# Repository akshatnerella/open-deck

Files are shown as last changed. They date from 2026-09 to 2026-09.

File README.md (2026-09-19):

# Open Deck

An open-source physical control surface for terminal AI coding agents.

Four project keys, a tuning dial, and a small face that tells you what your
agents are up to.

Built around **tmux**: the four animal keys are four tmux sessions, the encoder
steps through the panes inside one. Harness-agnostic — it works with Claude
Code, Grok CLI, OpenCode, or a plain shell, because it reads tmux rather than
integrating with any of them.

---

## Key map

```
 TERM   MIC    FOX    PNDA
 ENTER   X     CAT    OWL
```

| Key | Tap | Double-tap | Hold |
|---|---|---|---|
| **FOX OWL CAT PNDA** | go to that session — creates it if new | | list its panes |
| **TERM** | start the agent in this pane | new pane beside | new window |
| **X** | interrupt — `C-c` in a shell, `Escape` in an agent | close the pane | |
| **ENTER** | Enter — or go to the highlighted pane | | |
| **Encoder** | move through panes | | |

**One chord:** hold **ENTER** and double-tap **TERM** to split *below* instead
of beside.

Three behaviours worth knowing:

**ENTER, X and MIC change meaning with the pane.** `C-c` interrupts a shell but
`Escape` interrupts an agent without killing it; voice is `Space` in Claude and
`Ctrl-Space` in grok. In a plain shell MIC sends nothing at all — there's no
voice mode to toggle, and a stray space would type one.

**Starting an agent somewhere new is two presses:** double-tap TERM for an
empty pane, then tap TERM to fill it. One key never rearranges your screen as a
side effect of launching something.

**Tap X to stop it, double-tap X to close it.** Closing runs `exit`, so the
shell cleans up and tmux ends the session if it was the last pane. It refuses
while a program is running and toasts `still running` — tapping X already
interrupts, so the sequence is tap then double-tap.

---

## Setting it up on a Mac

Nothing to install for the host side: the bridge is **stdlib-only** and runs on
the Python that ships with macOS.

```bash
git clone git@github.com:akshatnerella/open-deck.git
cd open-deck
./open-deck                    # that's the whole install
```

You need **tmux** (`brew install tmux`) and an agent CLI on your `PATH`.

To have it start at login:

```bash
./scripts/autostart install    # uninstall / status also work
```

This copies the bridge to `~/Library/Application Support/OpenDeck` rather than
pointing at your checkout, because macOS blocks launchd agents from reading
`~/Documents`. Re-run it after pulling. Logs go to `~/Library/Logs/opendeck.log`.

### Flashing the deck

Only needed on a new board, not on a new Mac — the firmware lives on the
device.

```bash
arduino-cli core install esp32:esp32 \
  --additional-urls https://raw.githubusercontent.com/espressif/arduino-esp32/gh-pages/package_esp32_index.json
arduino-cli lib install "Adafruit GFX Library" "Adafruit SH110X"

arduino-cli compile --fqbn esp32:esp32:XIAO_ESP32S3 v0/firmware/open_deck
arduino-cli upload  --fqbn esp32:esp32:XIAO_ESP32S3 -p /dev/cu.usbmodemXXXX v0/firmware/open_deck
```

The eye renderer is vendored as `pixie_eyes.h`, so there's no third library to
install. See the notes at the top of that file for what's patched and why.

> **Using the Arduino IDE instead?** It keeps a *separate* config from
> `arduino-cli` — same sketchbook, different board packages. Add the Espressif
> URL under **Settings → Additional boards manager URLs**, then quit and reopen
> the IDE, or the board won't appear even though it's installed.

> **Only one thing can hold the serial port.** Close the IDE's Serial Monitor
> before running the bridge, and stop the bridge before flashing.

### Configuration

None required. The four keys already mean `fox`, `owl`, `cat`, `pnda`.

Optional, at `~/.config/opendeck/config.json`:

```json
{
  "harness": "grok",
  "sessions": ["webapp", "api", null, null]
}
```

`harness` is one of `claude`, `grok`, `opencode`, `codex`, `aider` — it picks
the launch command and the right keystrokes for ENTER, X and MIC. Detection
stays permissive: a deck set to grok still shows a Claude pane as working,
because the setting decides what a key *launches* and must not make the display
lie about what's running.

---

## What it does

**A key means the same session every time.** FOX is `fox`, CAT is `cat`. If it
doesn't exist yet, pressing the key creates it. Nothing is discovered, nothing
gets reshuffled — a physical button whose meaning moves is worse than no button.

**Hold a key to see inside.** The panel lists that session's panes: a mark for
shell or agent, the active one flagged, and whatever each pane is best called.
Claude Code reports a session title (`open deck`), which beats anything the deck
could infer. A plain terminal shows as `zsh` rather than being hidden.

**The dial browses.** In the session you're in it follows along — your Mac is
the preview. Hold an animal and it browses *that* session without moving you; a
dial shouldn't yank you out of what you're reading. ENTER goes to the
highlighted pane, switching sessions if it's elsewhere. Stop touching it and the
list gives up after a couple of seconds and goes back to Pixie. It's a
look-and-go tool, not a mode.

**The home screen is Pixie, and only Pixie.** She has the whole panel. Her
expression is driven by tmux state — concerned when something wants attention in
a session you aren't watching, happy when an agent finishes, curious while one
works.

**A live deck never lies about being live.** The bridge pings the display every
couple of seconds; if that stops, Pixie's eyes close and a `host offline` toast
appears within about five seconds, rather than leaving a stale face on screen.

### Attention

When a session you aren't looking at rings a bell or shows activity, the deck
inverts the whole screen three times, Pixie turns to a scowl, and a toast names
the session (`OWL wants you`). A standing alert re-pulses every 10s.

`invertDisplay()` is a single command byte rather than a framebuffer write, so
flashing is effectively free next to the ~29.5ms cost of a redraw.

A piezo buzzer would still beat any visual signal for catching attention when
you're looking elsewhere entirely — v1's PCB should populate one.

---

## Architecture

```
┌───────────────┐  USB serial  ┌─────────────────┐    tmux     ┌──────────┐
│   Open Deck   │─────────────▶│    opendeck     │────────────▶│ sessions │
│ XIAO ESP32S3  │  EVT / HB    │  (host bridge)  │  + Ghostty  │  panes   │
│               │◀─────────────│                 │◀────────────│  agents  │
└───────────────┘ FACE/TOAST/  └─────────────────┘   polling   └──────────┘
                  PEEK/LIST
```

The firmware knows nothing about tmux or any harness — it emits semantic events
(`EVT KEY_AGENT2 HOLD`) and renders whatever the host pushes back. All the
knowledge lives in the bridge, where it's testable without hardware.

**Everything is derived from tmux**, which already tracks per-window activity
and bell flags — the "something happened where you aren't looking" signal, free,
for every harness. No hooks, no `settings.json` edits, no screen scraping.

Keys reach panes with `tmux send-keys`: it hits the right pane **without
stealing focus** and needs no macOS Accessibility permission. The deck is
deliberately **not** a USB keyboard — see
[docs/decisions/no-hid.md](docs/decisions/no-hid.md) for why that was built
twice and removed twice.

---

## Versions

| | |
|---|---|
| **[v0](v0/)** | Hand-wired breadboard prototype. USB-tethered, off-the-shelf parts. **Built and working.** Start here |
| **v1** | Custom PCB with the XIAO reflow-mounted via castellated pads, proper diode matrix, piezo buzzer. Not started |

See [`v0/README.md`](v0/README.md) and [`v0/BOM.md`](v0/BOM.md).

---

## Status

| | |
|---|---|
| Hardware: display, encoder, 8-key matrix | ✅ validated |
| Firmware: input on core 1, rendering on core 0 | ✅ built |
| Host bridge: tmux navigation, peek, Pixie | ✅ built, 211 tests |
| Claude Code and Grok CLI | ✅ detection and keymaps measured on both |
| OpenCode / Codex / Aider | ⏳ patterns written, unverified against those CLIs |
| Custom PCB | 📋 v1 |

Tests run on stock macOS Python with no dependencies:

```bash
cd v0/bridge && python3 -m unittest discover -s tests
```

---

MIT licensed. Not affiliated with Anthropic, xAI, or any harness vendor.

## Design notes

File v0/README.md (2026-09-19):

# Open Deck v0

The hand-wired prototype: breadboard, off-the-shelf parts, USB-tethered.
**Everything here is built and verified working on real hardware.** The
`FACE`/`LIST` wire protocol and the glance layer are new — built and covered
by the host-side test suite, but not yet re-verified against the physical
deck.

v1 will replace the breadboard with a custom PCB — see the root
[README](../README.md).

---

## Contents

```
v0/
├── BOM.md                  parts list, wiring, print notes
├── firmware/
│   ├── open_deck/          THE firmware - flash this
│   │                       (pixie_eyes.h is a vendored, patched RoboEyes)
│   └── diagnostics/        bring-up sketches (i2c scan, key probe, ...)
├── bridge/
│   ├── opendeck/           host bridge (stdlib only)
│   └── tests/              211 offline tests, no hardware needed
├── cad/
│   ├── stl/                printable shells + 8 keycaps
│   └── dxf/                badge icon outlines (for remixing keycaps)
└── tools/
    └── serial_mirror_gui.py   mirrors the deck UI on your laptop
```

---

## Build order

1. **Print** the shells and keycaps — `cad/stl/`, see [BOM.md](BOM.md)
2. **Wire** it up — pin map in [BOM.md](BOM.md)
3. **Flash** the firmware:
   ```bash
   arduino-cli compile --fqbn esp32:esp32:XIAO_ESP32S3 firmware/open_deck
   arduino-cli upload  --fqbn esp32:esp32:XIAO_ESP32S3 -p /dev/cu.usbmodemXXXX firmware/open_deck
   ```

   > Build with the board's default USB mode (`hwcdc`). It uses the hardware
   > USB-Serial/JTAG peripheral, so the port exists whatever the firmware does
   > — a bad flash can always be recovered with another flash.
4. **Verify** the wiring before going further:
   ```bash
   arduino-cli upload --fqbn esp32:esp32:XIAO_ESP32S3 -p PORT firmware/diagnostics/i2c_scanner
   ```
   The OLED must appear at `0x3C`. If nothing shows up, it's the wiring or a
   charge-only USB cable — not the code.
5. **Run the bridge.** There is no install step — it is stdlib-only and runs
   on the Python macOS ships:
   ```bash
   ./open-deck --command grok
   ```

Everything is read from tmux — no hooks, no `settings.json` edits. Run your
agents under `tmux` and the deck picks them up automatically.

6. **Optionally run it at login**:
   ```bash
   ./scripts/autostart install     # uninstall / status also work
   ```
   Installs a launchd agent that restarts on crash and logs to
   `~/Library/Logs/opendeck.log`. It copies the bridge to
   `~/Library/Application Support/OpenDeck` — macOS blocks launchd agents from
   reading `~/Documents`, so pointing one at a checkout there fails. Re-run
   after pulling.

Optional config at `~/.config/opendeck/config.json`:

```json
{
  "launch_command": "grok",
  "sessions": ["webapp", "api", null, null]
}
```

---

## Diagnostics

If something misbehaves, these isolate it faster than guessing:

| Sketch | Answers |
|---|---|
| `i2c_scanner` | Is the display on the bus at all? |
| `raw_io_test` | Live pin states — is a key or the encoder actually wired? |
| `key_test` | Single-key press detection |
| `encoder_menu_test` | Encoder rotation with the debounced lookup-table decoder |
| `open_deck_validate` | Display + encoder + one key together |
| `open_deck_matrix` | Full 8-key matrix with an on-screen grid |
| `pixie_face_test` | Pixie cycling every emotion, standalone |

`tools/serial_mirror_gui.py` renders the deck's UI on your laptop from the
same serial stream — useful for telling "the display is slow" apart from
"the firmware is slow".

```bash
python3 tools/serial_mirror_gui.py
```

> The bridge itself needs nothing, but this tool is the exception: it needs
> `pyserial` and a real Tk. Apple's bundled Tcl/Tk 8.5.9 renders a blank
> window. `brew install python-tk@3.13`, `pip install pyserial`, and use that
> interpreter.

---

## Tests

```bash
bridge/tests/run_tests.sh
```

132 tests covering gesture timing, slot assignment, tmux actions, presence
resolution, pane-list formatting, config loading and event parsing. No
hardware or tmux required — everything is driven through fakes.

---

## Hard-won notes

Things that cost real debugging time, so you don't repeat them:

- **The display is SH1106, not SSD1306.** An SSD1306 driver renders
  plausible-looking garbage rather than failing cleanly.
- **Column order is `D7 D8 D9 D10` left to right** — the reverse of what the
  wiring notes implied. It was determined by pressing keys and reading back
  what the device reported. Measure, don't derive.
- **Serial writes must not block.** ESP32-S3 native USB CDC blocks once its TX
  ring fills with no host reading. Inline `Serial.print` in the main loop then
  stalls the key scan *and* the display. The firmware drops lines instead.
- **Don't redraw the OLED on a timer.** A full-frame I2C push is ~30ms; doing
  it 30×/second regardless of activity starves everything else. Redraw on
  change only.
- **`pinMode()` is expensive on ESP32.** Toggling rows between `OUTPUT` and
  `INPUT` every scan was slow enough to make the encoder feel laggy;
  `OUTPUT_OPEN_DRAIN` set once gives the same protection for free.
- **Scope input debouncing to the keys that need it.** A double-tap window
  held *every* tap for 350ms, though only one key had a double binding - so
  seven keys paid for a feature they never used. Latency you add deliberately
  is still latency.
- **A full OLED flush blocks for 29.5ms.** Sharing a thread with input means
  the encoder is never sampled during a flush, and detents get *dropped* —
  which reads as inconsistency, not lag. Rendering is pinned to core 0 and
  `loop()` owns core 1. Measured: 29,500µs blind window → 390µs.
- **Stay on the default `hwcdc` USB mode.** It was briefly built as
  `USBMode=default` (TinyUSB) to get HID, which cost three separate hazards:
  the port renamed between app and bootloader so uploads failed on the first
  pass, and a firmware that failed to bring up USB made its own port vanish.
  Under `hwcdc` the port is dedicated silicon and exists whatever the firmware
  does, so a bad flash is always recoverable with another flash.
- **A charge-only USB-C cable** will power the board and blink the charge LED
  while enumerating nothing. The LED tells you nothing about the data link.
- **A status display that lies is worse than none.** Without a host keepalive
  the deck happily showed a stale face forever. Any received command is a
  liveness tick; 5s of silence closes Pixie's eyes.

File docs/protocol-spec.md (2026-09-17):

# Open Deck — Wire Protocol v2

USB CDC serial, 115200 baud, newline-delimited ASCII, bidirectional.

Human-readable on purpose: `screen /dev/cu.usbmodemXXXX 115200` is a complete
debugging setup.

---

## Device → host

```
EVT <KEY_NAME> DOWN|HOLD|UP
EVT ENCODER <+1|-1>
HB <uptime_ms>
```

### Keys

| Name | Position | Bound to |
|---|---|---|
| `KEY_TERM` | R1C1 | launch agent / split / new window |
| `KEY_MIC` | R1C2 | voice toggle (Space; `C-Space` on grok) |
| `KEY_AGENT1` | R1C3 | Fox |
| `KEY_AGENT4` | R1C4 | Panda |
| `KEY_ENTER` | R2C1 | Enter |
| `KEY_CANCEL` | R2C2 | interrupt / close pane |
| `KEY_AGENT3` | R2C3 | Cat |
| `KEY_AGENT2` | R2C4 | Owl |

`HOLD` fires at 400ms while a key is still down. The host runs the *hold*
action on `HOLD`, and the *tap* action on `UP` **only if no `HOLD` was seen**
since the matching `DOWN`. Double-tap is resolved host-side within a 350ms
window. One physical press yields exactly one action.

---

## Host → device

```
FACE <alert|busy|done|calm>
TOAST <text>
LIST <title>|<row>|<row>|...
PEEK <cursor>|<bar>|<row>|...
```

`FACE` sets Pixie's expression, one of four wire states. The old
`idle`/`working`/`attention`/`done`/`active`/`asleep` set is gone —
`idle`/`active` rendered identically and `asleep` was presentation rather
than a state of its own, so the daemon now resolves everything down to
`alert`, `busy`, `done`, or `calm` (see `presence.py`).

`TOAST` shows one line for 1.8s, replacing the face, then the face resumes.

`LIST` shows the pane list for whichever session the encoder or a project key
just brought into view — a title row plus up to five pane rows — held for
1.2s, then decaying back to the face. Summon sends `LIST` too, in place of a
toast, because naming the destination and showing its contents in one shot is
strictly more useful than a line of text.

`PEEK` leads with the **cursor**: the row index the device draws inverted, or
`-1` for no selection. Inverting a row says "ENTER goes here" instantly and
costs no width, which a marker character would.

`PEEK` then carries rows, because the device positions each
by role rather than stacking them: an inverted **bar** naming the key, a
**headline** the panel is built around, and a small **detail** line. The
headline is drawn at double size when it fits in 10 characters and normal size
otherwise, so a short session name reads across a desk and a long one still
reads at all.

`PEEK` shows what a held key will do, replacing everything else on screen. It
has no timeout: it goes up when the hold registers and comes down when the key
is released, so it tracks the finger. An empty payload clears it.

Peeking is non-destructive by design. Holding used to interrupt that slot's
session; a destructive action on the same gesture teaches people not to
explore, which defeats the point of a self-documenting device.

`LIST` travels as **one line**, never a begin/item/end sequence. A multi-line
render can be interrupted mid-draw by whatever the host sends next, leaving a
half-built screen on the panel; a single line either arrives complete or not
at all. The host does every formatting decision — windowing to five rows with
the active pane always kept visible, the `>` active marker, tmux window
flags, label truncation and delimiter sanitisation, all in `panes.py` — and
hands the firmware one `|`-delimited string. The firmware only splits on `|`
and draws each field verbatim; it makes no layout decisions of its own.

Toast and list both **replace** rather than overlay the face: RoboEyes'
`drawEyes()` flushes the framebuffer itself, so an overlay would need a
second full-frame write every frame. Each is drawn and flushed once and then
costs nothing until it expires.

---

## Liveness

The host sends `FACE <state>` every 2s regardless of whether the state
changed — a keepalive, not just a state push. The firmware treats **any**
received command as proof the host is alive; after 5s of silence it closes
Pixie's eyes and shows a `host offline` toast. This is deliberate: without a
keepalive the deck would happily keep showing a stale face forever after the
daemon died, and a status display that can go stale silently is worse than no
display. `lastHostCommand` is seeded at boot, so a deck powered on before the
daemon connects doesn't slam its eyes shut in the first few seconds.

An offline deck that stays offline blanks the panel entirely after 15
minutes, to avoid burning a static image into the mono OLED.

---

## Hardware notes

Verified by pressing R1C1..R2C4 in sequence and reading back what the device
reported:

| | |
|---|---|
| Rows | `D0` (row 1), `D1` (row 2) |
| Cols | `D7 D8 D9 D10` — **left to right** |
| Display | SH1106 128×64, I2C `0x3C`, on `D4`/`D5` |
| Encoder | CLK `D3`, DT `D6`; push-switch dead/unused |

Column order is the reverse of what the wiring diagram suggests. It was
measured, not derived. Don't re-derive it.

---

## Three constraints the firmware is built around

**Rendering runs on the second core.** A full SH1106 flush blocks for
**29.5ms** (measured), and RoboEyes wants a frame every 20ms — so on one
thread the display saturates the loop and the encoder is never sampled during
a flush. Detents last a few milliseconds, so they were not arriving late, they
were being *dropped*. Rendering is pinned to core 0; `loop()` owns core 1 for
input alone. Measured effect: worst input blind window 29,500µs → 390µs, loop
rate 1,100/s → 3,704/s.

**Serial writes drop rather than block.** ESP32-S3 native USB CDC blocks once
its TX ring fills with no host reading. `emit()` checks
`Serial.availableForWrite()` first. An unguarded `Serial.printf` was measured
stalling the loop for 1.8s while no host was attached.

**Rows are `OUTPUT_OPEN_DRAIN`.** LOW sinks, HIGH releases rather than
sources, so two keys sharing a column across both rows cannot short one row's
output into the other.

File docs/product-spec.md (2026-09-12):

# Open Deck — Design Notes

Why the device is shaped the way it is. For protocol details see
[protocol-spec.md](protocol-spec.md); for building one see
[../v0/README.md](../v0/README.md).

---

## The idea

Running several coding agents at once, the bottleneck isn't typing — it's
**context switching**. Which project was that in? Which pane is the agent in?
Where did I leave the tests running?

The deck maps that onto hardware you can hit without looking:

- **Four animal keys → four tmux sessions.** Coarse: which project.
- **Encoder → panes within that session.** Fine: which terminal.

The key insight, and the one that came from the user rather than the design:
**tmux sessions are a real thing you already have.** An earlier version
invented "agent sessions" as an abstraction and asked you to adopt it. Mapping
to tmux instead means the deck fits an existing workflow rather than replacing
one, and it makes the hardware's job legible — a preset button and a tuning
dial, like a radio.

---

## Why tmux does most of the work

tmux already tracks, per window, whether there's been **activity** or a
**bell** since you last looked. That's precisely the "something happened where
you aren't watching" signal the device needs — available from one subprocess
call, with no agent integration, no hooks, and no screen scraping.

An earlier design got this from Claude Code's hook system. That worked, but it
was Claude-Code-specific, needed `settings.json` edits, and broke entirely
under `--dangerously-skip-permissions`. tmux gives the same signal for every
harness for free.

---

## Pixie

The face is [Pixie](https://github.com/akshatnerella/pixie), drawn
procedurally by RoboEyes — the same character, ported from her 320×240 colour
panel to the deck's 128×64 mono OLED. Her expression is derived from tmux
state, evaluated in strict priority order so two simultaneously-true signals
can't make the face flap:

| Priority | State | Trigger |
|---|---|---|
| 1 | `attention` | activity/bell in a session you are **not** in |
| 2 | `done` | an agent that was running here stopped |
| 3 | `working` | something is running in the current session |
| 4 | `active` | you touched the deck (4s linger) |
| 5 | `idle` | shells only |
| 6 | `asleep` | 5 min untouched, or no sessions |

`done` is explicitly non-latching, or she'd stay grinning forever.

Notifications are **toasts**: one line, 1.8s, replacing the face. Subtle by
construction — they interrupt briefly rather than becoming permanent chrome.

---

## Things learned the hard way

Each of these cost real debugging time and is now pinned by a test or a
comment in the code.

**The display was eating the encoder.** A full SH1106 flush blocks 29.5ms;
RoboEyes wants a frame every 20ms. On one thread the encoder was never sampled
during a flush, so detents weren't delayed — they were dropped. Fixed by
pinning rendering to the second core. This looked like host-side lag and
wasn't; measuring the host first (12ms/poll, 7ms/detent) ruled it out before
any code changed.

**Claude Code reports its version as the process name.** `pane_current_command`
returns `2.1.261`, not `claude`. An allowlist of binary names silently misses
every running agent. Matched by shape as well as name.

**Column order was mirrored.** Physical left-to-right is `D7 D8 D9 D10`, the
reverse of the wiring diagram. Determined by pressing keys in sequence and
reading back the reported names. Guessed twice, wrong twice; measuring took one
round.

**Ghostty needs `-e` with separate argv entries.** `--args -e "tmux attach -t x"`
opens a window that runs nothing. And it uses non-native fullscreen, so
`AXFullScreen` reads `false` even when fullscreen — a "toggle unless already
fullscreen" check exits fullscreen every time. Fullscreen is set at launch
only.

**Never type into a busy pane.** `launch_agent` refuses when the pane is
running a program; injecting a command into someone's editor is unrecoverable.
The double-tap split path skips the check because a fresh pane is always an
idle shell.

---

## Not built

**Approvals.** A physical approve/deny button for agent permission prompts was
designed and built, then removed: it depends on the harness *asking*, and the
day-to-day launch command here is `grok`, which does not gate tool use.
The two are mutually exclusive by construction. The design notes are in git
history if that changes.

**A buzzer.** The deck still can't get your attention when you aren't looking
at it; a flashing face in peripheral vision is a weak signal. One chirp on
"agent blocked" would be worth more than every visual affordance here. v1's PCB
should populate one.

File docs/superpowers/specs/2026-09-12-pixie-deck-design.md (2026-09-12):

# Pixie Deck — product design

**Status:** proposed
**Date:** 2026-09-12
**Supersedes:** the "control surface for tmux" framing in `docs/product-spec.md`

Turns the deck from a tmux accessory into a desk product: four projects, four
keys, a character who tells you how they are doing. tmux stays — as plumbing
the owner never sees.

---

## Why it currently feels like a tool

Three concrete things, all fixable:

**1. It assumes tmux fluency.** `SlotTable` binds keys to sessions that already
exist. You create sessions, you name them, and the deck finds them. A key
pointing at nothing does nothing — so the device is inert until you have
already done the work by hand.

**2. Setup is a text file.** Pinning a slot means editing
`~/.config/opendeck/config.json` and restarting. Nothing about the physical
object participates in its own configuration, even though it has a screen, a
scroll wheel, and eight buttons.

**3. Every feature is a tmux command wearing a costume.** `summon` is
`switch-client`. The encoder is `select-pane`. The animals are decoration on
top of a keybinding you already had. There is no reason to want the object.

The fix is one decision: **the deck owns the projects, not the sessions.**

---

## The reframe

> Four keycaps. Four projects. Press one and you are working on it.

A slot is a **project** — a directory with a name and an animal. The deck
creates its session, opens the terminal, launches the agent, and remembers.
The owner never types `tmux`, never names a session, never edits a config.

| | Tool (today) | Product |
|---|---|---|
| A key means | a tmux session that exists | a project you work on |
| Empty key | does nothing | offers to set itself up |
| Binding | edit JSON, restart | encoder + press, on the device |
| Requires | knowing tmux | knowing which project you want |
| tmux is | the interface | an implementation detail |

Everything below follows from that.

---

## First run

The moment that decides whether this is a product. Plug in a deck that has
never been used:

```
1.  Pixie wakes, stretches, blinks.          "hello"
2.  The slot strip shows four empty pens.    · · · ·
3.  Press any animal key.
4.  The picker opens: recent git repos,
    most-recently-touched first.             turn to choose
5.  Press to confirm.
6.  The deck creates the session, opens the
    terminal, launches the agent.            FOX -> open-deck
```

Under a minute from plugging in to an agent running, with no typing. That is
the demo.

**Project discovery** scans for git repositories under the usual roots
(`~/Developer`, `~/Documents`, `~/src`, `~/code`, `$HOME`), ranked by most
recent commit — the same ordering an editor's "recent projects" uses, and it
is right nearly every time. No index, no daemon config: the scan runs when the
picker opens and caches for the session.

**Binding is remembered** in `~/.config/opendeck/decks.json`, written by the
deck, not by the owner. It is a cache with an obvious shape, not a config file
with a schema to learn. Deleting it costs one re-pick.

---

## The display, as a designed system

Five screens. Every pixel has an owner, and transitions between them are
defined rather than incidental.

### Home — Pixie, plus the fleet at a glance

```
+---------------------+
|                     |
|      ^   ^          |
|     ( o   o )       |    Pixie: 48px
|        ---          |
|                     |
+---------------------+
| FOX. OWL@ CAT! PNDA |    slot strip: 16px
+---------------------+
```

The slot strip is the product's whole value in one row: four projects, four
states, readable from across a desk without focusing your eyes.

| Glyph | State |
|---|---|
| (blank) | slot is empty |
| `.` | idle — a shell, nothing running |
| `@` | working — an agent is busy (animates) |
| `!` | needs you — blocked, or asking |
| `*` | done — finished since you last looked |

Pixie's expression is the same information at lower resolution: one glance
tells you *whether* anything needs you, the strip tells you *which*.

### Peek — hold any key

Holding a key shows what it will do, laid out in the same 2×2 arrangement as
the physical keys under your other hand. A chord system nobody can discover is
a party trick; this makes the device teach itself, and removes the manual.

```
Hold FOX:            +---------------------+
                     | FOX  open-deck      |
                     | working  ctx 62%    |
                     |---------------------|
                     | new    | interrupt  |
                     | speak  | approve    |
                     +---------------------+
```

Release without a second key and nothing happens — peeking is free, which is
what makes it safe to explore.

### Picker — encoder

A list bound to the encoder: projects when a slot is empty, panes when it is
not. Press to commit, any other key to cancel.

### Alert — something needs you

Pixie scowls, the strip marks the slot, a line names it. Latches until
acknowledged, because the whole point is that you were not looking.

### Sleep

After five idle minutes the panel blanks except for Pixie breathing. The deck
is furniture that occasionally has something to say, not a dashboard demanding
attention.

---

## Input grammar

The physical layout is already right and nobody planned it:

```
TERM   MIC     FOX   PNDA        left hand: verbs
ENTER  CANCEL  CAT   OWL         right hand: targets
```

Verbs under one hand, targets under the other. That is a two-handed chord
keyboard, so the grammar is **verb + target**:

| Input | Meaning |
|---|---|
| Tap target | go to that project (set it up if empty) |
| Hold target | peek: status + what the verbs will do |
| Hold target, turn encoder | scrub that project's panes without leaving yours |
| Hold target, tap verb | **apply the verb there without going there** |
| Tap verb | apply to where you are |
| Turn encoder | move between panes here |
| Hold TERM, turn encoder | command palette |

The fourth row is the one tmux cannot do and the reason to own the object:
**interrupt the agent in CAT while you keep reading OWL.** Every keybinding
alternative requires switching first.

Double-tap stays reserved for one shortcut per key, assigned from real use
rather than invented now. Today's `KEY_TERM` double-tap-to-split is the
template.

### One thing to fix

Slot numbering does not match reading order: `FOX PNDA / CAT OWL` on the keys,
but slots 0–3 are `FOX OWL CAT PNDA`. Harmless internally, wrong the moment a
screen lists them in slot order. Renumber to match what the eye sees.

---

## Pixie as the product, not the paint

She already earns her place: her expression is derived from real state, in
strict priority order, so two true signals cannot make the face flap. Three
additions make her the reason to keep the thing on a desk.

**She reacts to you, not just to the agents.** Coming back after ten minutes
away should look different from never having left. The deck knows — it sees
key events.

**She has an opinion about time.** An agent working for two minutes is normal;
one stuck for twenty is worth a worried look, and nothing in the current state
machine can express that.

**She is never wrong.** The existing offline rule — eyes closed when the host
stops talking — is the single most important thing about her, and it stays.
A face that keeps smiling when it has no idea what is happening is worse than
a blank screen, because it is confidently wrong.

What she does **not** get: voice, wake word, or a brain. Those are Pixie the
companion's job, in Pixie's repo. Here she is a character and a status
display, which is exactly enough.

---

## What gets deleted

Productising is mostly subtraction:

- **Hand-editable `config.json`** as the binding mechanism. The deck writes
  its own bindings. Keep a config for genuine preferences (launch command,
  terminal) and stop pretending session pinning is a preference.
- **`profiles/`** as a user-facing directory. Harness differences become
  detection plus one question at first run.
- **"Run your agents under tmux and the deck picks them up"** from the README.
  That sentence is the tool framing in one line.
- **Slot assignment by discovery.** Sticky-on-first-sight is clever and
  unpredictable. Bindings are explicit, owned, and visible.

---

## Build order

| Phase | Deliverable | Proves |
|---|---|---|
| 1 | Slot strip on the home screen | the glanceable-fleet claim |
| 2 | Peek on hold | the device teaches itself |
| 3 | Project picker + `decks.json` | no config file, no tmux |
| 4 | Create-on-empty: session, terminal, agent | a key always does something |
| 5 | Verb+target chords | the thing keybindings cannot do |
| 6 | First-run flow end to end | the demo |

Phases 3 and 4 are the product. 1 and 2 are worth shipping first because they
are visible, self-contained, and make the next three easier to judge.

---

## Open questions

**More than four projects.** Four keycaps, more repos. Options: hold-encoder
to page between banks of four; or accept four as the product's opinion. Worth
resisting the urge to solve now — four may simply be the right number, and
"an opinion" is a product property.

**The bridge is still a launchd script.** One command, but a shell script.
A signed menu-bar app is the honest end state and a real amount of work;
worth doing only once the rest is settled.

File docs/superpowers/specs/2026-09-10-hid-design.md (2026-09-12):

# Open Deck — HID Design

**Status:** REJECTED — built, then removed. See
[docs/decisions/no-hid.md](../../decisions/no-hid.md).

> Kept for the record. The reasoning below is wrong: it treats HID's
> inability to address a pane as a limitation to work around, when it is
> the reason the approach cannot work.
**Date:** 2026-09-10

Makes the deck work as a plain USB keyboard on a machine with nothing
installed, while keeping the full tmux experience where the daemon is running.

---

## Why

Today the deck is inert without its daemon. Plugging it into another Mac means
cloning the repo, building a venv, installing `pyserial`, having tmux, and
running a launchd agent. A macro pad that needs a Python daemon on every
machine is not really a peripheral — it is software with a keyboard attached.

The ESP32-S3 can enumerate as **HID keyboard and CDC serial at the same time**,
which gives the device two tiers:

| Tier | Needs | Gets |
|---|---|---|
| **Bare** | nothing | keys send real keystrokes |
| **Bare + 6 lines of `.tmux.conf`** | tmux | session switching too |
| **Full** | the daemon | targeted delivery, Pixie, the pane list |

The deck degrades instead of dying.

## Goals

1. Keys do something useful on a machine with nothing installed.
2. The full experience is unchanged where the daemon runs.
3. No double-firing: a keypress never produces two actions.
4. Nothing already built is thrown away — same protocol, same daemon.

## Non-goals

- Replacing the daemon. HID is strictly less capable (see below).
- Mouse, consumer-control or gamepad HID.
- Configuring the HID keymap at runtime.

---

## The central constraint

The board currently builds as **`USBMode=hwcdc`** — the hardware USB-Serial/JTAG
peripheral. macOS enumerates it as `USB JTAG_serial debug unit`. That peripheral
**cannot do HID at all**.

HID requires **`USBMode=default`** (USB-OTG / TinyUSB), which supports a
composite HID+CDC device. Verified: both a HID sketch *and* the existing
firmware compile unchanged under that FQBN.

```
esp32:esp32:XIAO_ESP32S3:USBMode=default
```

Cost: ~43KB flash (9% → 11%) and ~2KB RAM. No code rewrite.

**This FQBN must be pinned everywhere** — README, `v0/README.md`, and any build
script. A build with the default FQBN silently produces a device with no HID
and no obvious symptom beyond "the keys stopped working on my other laptop".

---

## HID keymap

Only fires when the daemon is absent (see arbitration).

| Key | HID output | Rationale |
|---|---|---|
| ENTER | `Return` | Claude Code submits and accepts prompts with it |
| X | `Escape` | Claude Code interrupts and denies with it |
| MIC | `Space` | the voice-mode toggle |
| FOX / OWL / CAT / PANDA | `F13` / `F14` / `F15` / `F16` | bindable, collide with nothing |
| TERM | `F17` | ditto |
| Encoder − / + | `F18` / `F19` | ditto |

`F13`–`F24` are real HID keycodes that essentially no application binds by
default — verified present in the core's `USBHIDKeyboard.h` as `0xF0`–`0xFB`.
That makes them safe to send blind on an unknown machine: on a bare box they do
nothing, and where the user wants more they are free to bind.

### The zero-install tmux tier

Six lines gets session switching with no daemon at all:

```tmux
bind-key -n F13 switch-client -t fox
bind-key -n F14 switch-client -t owl
bind-key -n F15 switch-client -t cat
bind-key -n F16 switch-client -t pnda
bind-key -n F18 previous-window
bind-key -n F19 next-window
```

Ship this as `v0/bridge/scripts/opendeck.tmux.conf` with a one-line install note.

Note the encoder degrades here: HID mode cycles *windows*, not panes, because
tmux has no built-in "next pane across the session" binding. That is a real
capability loss and belongs in the docs, not hidden.

---

## Arbitration: never two actions from one press

The danger is obvious — if HID and the daemon both act, pressing X sends
`Escape` **and** the daemon sends `C-c`.

The device already knows whether a host is alive: the offline watchdog built
for the face. Reuse that signal rather than inventing a second one.

**Host alive → serial only. Host absent → HID only.**

But a single threshold is wrong here, because the two failure modes differ:

| Situation | Threshold | Why |
|---|---|---|
| No host has *ever* spoken since boot | **5s** (the existing boot grace) | this is a bare machine; make the keys work quickly |
| A host spoke, then went quiet | **15s** | probably a hiccup — a slow tmux call, a daemon restart |

The asymmetry matters. With one short threshold, a daemon that stalls for six
seconds would silently start typing `Escape` into whatever window happens to be
focused — possibly a browser. Requiring a longer, deliberate absence before
arming HID makes that misfire implausible while still recovering automatically.

This is the one place where the watchdog stops being cosmetic and starts
gating behaviour, so it needs saying plainly: **a long daemon outage changes
what the keys do.** The display already announces it (eyes closed, `host
offline`), which is the honest signal that the deck is in its degraded tier.

### State

```c
bool hostEverSeen;              // set on the first host command after boot
unsigned long lastHostCommand;  // already exists
```

```
hidArmed = !hostAlive && (hostEverSeen ? absent > 15s : absent > 5s)
```

`hidArmed` is computed on the input core, since that is where key events are
handled. It is a read of a `volatile` word written by the same core — no new
cross-core state, no new mutex.

---

## What HID cannot do

Worth stating so nobody expects otherwise:

**HID types into the focused window.** It cannot target a pane. The daemon's
`tmux send-keys` reaches the right pane regardless of focus; HID cannot. So the
bare tier can interrupt *what you are looking at*, not "agent 3 over there".

**No pane list, no Pixie state.** Those need a host to compute them. On a bare
machine Pixie sits in her offline face, which is accurate — there is no host.

**The encoder loses pane granularity** in the tmux tier, as above.

HID is a graceful degradation, not a second implementation of the product.

---

## Risk: flashing gets sharper teeth

Under `hwcdc`, the serial port is produced by dedicated silicon and exists
whatever the firmware does. Under TinyUSB, **the firmware creates the port**. A
build that fails to bring up USB makes the port vanish, and recovery is the
BOOT-button sequence rather than a plain re-flash.

This project has already lost hours to a board that would not enumerate, so the
recovery path goes in the docs *before* it is needed:

1. Unplug.
2. Hold **BOOT**.
3. Plug in, keep holding ~2s, release.
4. Flash normally — the bootloader's port is independent of app firmware.

Keep `CDCOnBoot=Enabled` (already the default) so the port comes up before
`setup()` runs, which means even a hanging sketch stays flashable.

---

## Build order

| Phase | Deliverable |
|---|---|
| 1 | Switch FQBN to `USBMode=default`, flash, confirm the serial port and the daemon still work end to end. **Nothing else changes.** |
| 2 | Add `USBHIDKeyboard`, the keymap, and `hidArmed` arbitration |
| 3 | `opendeck.tmux.conf` + docs, including the degradation table and BOOT recovery |
| 4 | Verify on a second Mac with nothing installed |

**Phase 1 is the gate.** It is a one-line change that proves the USB mode switch
survives on real hardware before any HID code is written. If the port does not
come back cleanly, that is worth knowing while the diff is one line — not
buried under a keymap.

Phase 4 is the only phase that proves the point of the whole exercise.

---

## Open question for later

Should the daemon *suppress* HID explicitly rather than relying on silence — a
`HID off` command on connect, `HID on` at shutdown? It would make the handoff
deterministic instead of timing-based.

Deliberately deferred: it adds protocol surface and a failure mode of its own
(a daemon killed with `SIGKILL` never sends the re-enable, leaving HID dead
until reboot). The timing rule recovers on its own from every failure,
including the ones nobody planned for. Revisit only if the 15s rule misfires in
real use.

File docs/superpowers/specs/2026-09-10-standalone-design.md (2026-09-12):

# Open Deck — Standalone Design

**Status:** REJECTED — built, then removed. See
[docs/decisions/no-hid.md](../../decisions/no-hid.md).

> Kept for the record. The reasoning below is wrong: it treats HID's
> inability to address a pane as a limitation to work around, when it is
> the reason the approach cannot work.
**Date:** 2026-09-10

Makes the deck a complete control surface with no daemon, and lets the daemon
upgrade it rather than enable it.

---

## The idea

Everything the daemon *does* is expressible as keystrokes, because **tmux
intercepts its prefix regardless of what is running in the pane**. `C-b :`
opens tmux's command prompt over the top of Claude Code, vim, anything.

```
C-b :  switch-client -t fox  ⏎
```

That works on any machine with tmux, **with no configuration at all**. An
earlier HID attempt sent `F13`-`F19` and required `.tmux.conf` bindings on
every machine, which is why its bare tier was worthless — three keystrokes you
already had. Typing real tmux commands needs nothing.

## Goals

1. Every key does its real job with no daemon and no config.
2. The display shows something true when alone, and everything when not.
3. The daemon upgrades the deck rather than enabling it.
4. No key can do two things at once.

## Non-goals

- Replacing the daemon. It stays strictly better (see Limits).
- Running an agent on the device.
- Wireless. Different project.

---

## Actions, standalone

| Key | Keystrokes sent | Config |
|---|---|---|
| FOX / OWL / CAT / PANDA | `C-b :` `switch-client -t <name>` `⏎` | none |
| TERM | `C-b %` then `<launch-command>` `⏎` | none |
| TERM (hold) | `C-b c` — new window | none |
| Encoder + / − | `C-b :` `select-pane -t :.+` / `:.-` `⏎` | none |
| X | `C-c` | none |
| MIC | `Space` | none |
| ENTER | `Enter` | none |

Session names are the slot labels lowercased — `fox`, `owl`, `cat`, `pnda`.
That already matches what the daemon names a session when it creates one for an
empty slot, so the two tiers agree without coordination.

### Two guards become unnecessary rather than missing

The daemon refuses to type a launch command into a pane running vim, because it
can see `pane_current_command`. A standalone deck cannot see that — so **TERM
always splits first**. A freshly split pane is always an idle shell, so the
check is not needed rather than skipped.

Likewise X sends only `C-c`, never `exit`. The daemon's "close an idle pane"
behaviour needs state; dropping it standalone means X can never destroy a pane
by mistake.

---

## The display, standalone

The rendering already lives on the device — the host only ever sends semantic
lines like `FACE busy`. The missing piece is data, and a keyboard cannot read.

### Dead reckoning: what the deck knows because it did it

| Knowable alone | Because |
|---|---|
| current session | the deck sent `switch-client` |
| selected slot | the deck tracks its own key presses |
| panes it created | the deck sent `split-window` |
| launch command in flight | the deck typed it |

That is enough for a truthful header (`FOX · fox`) and an idling Pixie.

**Dead reckoning drifts** the moment you use the real keyboard, and a status
display that drifts silently is worse than one that admits ignorance. So
standalone mode renders only what the deck did itself, and Pixie sits in a
neutral face rather than claiming to know what agents are doing.

### The loop that would close it, and why it is not the default

The deck is also a serial device the host can write to. It can type:

```
C-b : run-shell "tmux list-panes -a -F '…' > /dev/cu.usbmodem*" ⏎
```

and the host writes the answer straight back to the deck's own CDC endpoint.
`run-shell` executes regardless of what occupies the pane. Verified: a bare
`printf 'LIST …' > /dev/cu.usbmodem1101` drives the display with no daemon
running at all, so the return path is real.

**It is refresh-on-keypress only, never a timer.** Every poll injects
keystrokes into whatever currently has focus; a browser receiving
`C-b :run-shell…` every two seconds is unacceptable. Refreshing right after the
user pressed a deck key is safe, because they have just demonstrated they are
looking at the terminal.

Which means standalone state is *fresh when you act and stale afterwards* — the
opposite of a status display. Hence: opt-in, off by default.

---

## Arbitration

The device already knows whether a host is talking — the offline watchdog built
for the face. Reuse it, with the asymmetry proven necessary before:

| Situation | Threshold | Behaviour |
|---|---|---|
| No host has ever spoken | 5s | standalone: keystrokes + dead reckoning |
| Host spoke, then went quiet | 15s | standalone |
| Host talking | — | serial only; no keystrokes at all |

The long warm threshold exists because a daemon that stalls for six seconds
must not start typing `C-b :` into a browser. That failure mode is why the
earlier HID attempt needed it, and it applies unchanged here.

---

## Limits — the daemon stays strictly better

**Keystrokes go to the focused window.** The deck cannot target a pane; the
daemon's `tmux send-keys` can. Standalone acts on what you are looking at.

**No unsolicited events.** A keyboard cannot learn that an agent finished,
became blocked, or filled its context while it was not typing. Every one of
those is exactly the product's original premise — *which agent needs me* — and
none survive without a host.

**Encoder loses cross-window cycling.** `select-pane -t :.+` walks panes within
the current window; "next pane anywhere in the session" has no built-in tmux
command and is computed by the daemon.

So standalone is a complete *controller* and half a *display*. The half it
loses is the half the product was for — which is the honest reason the daemon
is not going away.

---

## Cost

HID requires `USBMode=default` (TinyUSB), which brings back:

- the serial port renaming between app and bootloader modes
- two-pass flashing, since the port moves under esptool mid-upload
- a firmware that fails to bring up USB makes its own port vanish (BOOT-button
  recovery)

That is a real tax, accepted this time because the standalone tier is the whole
control surface rather than three keystrokes.

**Every HID write must be gated on `tud_hid_n_ready()`.**
`USBHIDKeyboard::write()` sends two reports and `SendReport` defaults to a
100ms timeout, so writing to an unready endpoint stalls the input loop for up
to 200ms per keypress — the same class of bug that forced rendering onto the
second core, an order of magnitude worse.

---

## Build order

| Phase | Deliverable |
|---|---|
| 1 | `USBMode=default`, HID keyboard, `tud_hid_n_ready()` gate, arbitration — nothing typed yet |
| 2 | tmux command-prompt macros for every key |
| 3 | Dead-reckoned display for standalone mode |
| 4 | Verify: keys drive tmux with the daemon stopped; nothing types with it running |

Phase 4 is the only one that proves the point.

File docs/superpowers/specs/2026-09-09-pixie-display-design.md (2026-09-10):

# Open Deck × Pixie — Display Design

**Status:** approved, not yet implemented
**Date:** 2026-09-09

Wires [Pixie](https://github.com/akshatnerella/pixie) into Open Deck as the
device's interface layer rather than as decoration, and makes the OLED
genuinely useful without turning it into a dashboard.

---

## Goals

1. The display is informative when you need it and calm when you don't.
2. Every state is unmistakable at a glance on a 128×64 mono panel.
3. The display never lies about whether it is live.
4. No new hardware, no new dependencies, no new keys.

## Non-goals

- Menus or configuration on the device
- Per-pane detail views (the terminal already is one)
- Sound
- Any second screen or mode the user can get stuck in

---

## Model: three layers, separated by time

A 128×64 mono display can be a character or a dashboard. Splitting the screen
between them does both badly. Splitting by *time* does not.

| Layer | Trigger | Decay |
|---|---|---|
| **Ambient** | default | — (resting state) |
| **Glance** | encoder turn, session summon | 1.2s after last interaction |
| **Alert** | attention state entered | 1.8s toast, face persists |

The device owns all decay timing. The host says *what* to show, never for how
long. This keeps timing behaviour in one place and makes the host stateless
with respect to the display.

---

## Face states

Four semantic states. The previous six included `idle` and `active`, which
rendered identically — two states that look the same are one state — and
`asleep`, which is a presentation concern rather than a meaning.

| Wire name | Pixie | Meaning |
|---|---|---|
| `alert` | `ANGRY`, idle motion off, screen flash | something wants you now |
| `busy` | `DEFAULT` + curiosity on | agents are working |
| `done` | `HAPPY` + `anim_laugh()` | finished — go look |
| `calm` | `DEFAULT`, autoblink + idle motion | nothing happening |
| `offline` | `close()`, no motion | host not talking (see below) |

`offline` is a presentation override, not a semantic state — the host never
sends it. Transitions settle through `DEFAULT` first, as today, because moving
directly between two eyelid shapes leaves erase artifacts.

`done` must remain non-latching (already covered by an existing test).

### Host → state mapping

Priority order, unchanged from the current `PresenceMonitor`, with the last two
rows collapsed:

| Priority | Condition | State |
|---|---|---|
| 1 | activity/bell in a session that is not current | `alert` |
| 2 | an agent that was running in the current session stopped | `done` |
| 3 | anything running in the current session | `busy` |
| 4 | otherwise | `calm` |

`ACTIVE_LINGER` and the `ASLEEP` branch are deleted. Recent-input feedback is
already served by the glance layer and toasts.

---

## Glance: the pane list

Shown while the encoder is turning, and on session summon.

```
FOX webapp       2/4
─────────────────────
  1 claude
> 2 nvim
  3 npm test
```

- Header: slot label, session name, active pane position / total
- At most 5 rows, windowed host-side so the active pane is always among them
- `>` marks the active pane
- A trailing `*` or `!` marks activity or bell on the window that pane belongs
  to (tmux tracks these per window, not per pane)
- An empty session renders a single `(empty)` row

### Pane labels

A pane's label is, in order of preference:

1. A deliberate window name (not a generic shell name)
2. `claude` / `grok` / `opencode` when `presence.is_agent()` matches —
   **including the version-string form**, so a Claude Code pane reads `claude`
   rather than `2.1.261`
3. `pane_current_command`

Labels are truncated to 13 characters and sanitised host-side: `|` and
whitespace become `_`, because `|` is the wire delimiter.

### Summon shows the list

Pressing an animal key currently toasts `FOX - webapp`. That names the
destination but not its contents. It will show the pane list instead — strictly
more information, and one fewer concept to explain.

Toasts remain for events that are not list-shaped: `cla started`,
`OWL interrupted`, `OWL wants you`, `host offline`.

---

## Protocol

Replaces `STATE` and keeps `TOAST`.

```
FACE  <alert|busy|done|calm>
TOAST <text>                          1.8s, then face
LIST  <title>|<item>|<item>…          1.2s, then face
```

`LIST` is deliberately a **single atomic line**. A begin/item/end sequence can
be interrupted midway and leave the device rendering a half-built screen; one
line cannot. At 21 characters × 6 rows the payload fits well inside the
existing 200-character line buffer.

Example:

```
LIST FOX webapp 2/4|  1 claude|> 2 nvim|  3 npm test
```

The device splits on `|`: the first field is the title, the rest are rows,
rendered verbatim after truncation to 21 characters. Each `LIST` resets the
1.2s hold, so continuous encoder turning keeps the screen alive without the
host tracking duration.

**The host formats and windows the list**; the device only draws it. The host
sends at most 5 rows, already scrolled so the active pane is among them, with
markers and flags applied. This keeps every formatting rule in one testable
place and leaves the firmware a dumb renderer.

### Liveness

The host sends `FACE <state>` every 2s regardless of change. The firmware
already early-returns when the state is unchanged, so this restarts no
animation. The device treats *any* received command as a liveness tick.

No command for **5s** → `offline`: eyes close, idle motion stops, and a
`host offline` toast fires once on entry. This is unmistakably different from
`calm`, which is awake and blinking.

Recovery is automatic on the next command received.

---

## Burn-in

Mono OLEDs retain. Two cases:

- **`calm`** — idle motion stays on, so the eyes wander naturally. No extra
  work needed.
- **`offline` beyond 15 minutes** — the panel is blanked entirely. Nothing live
  is being shown, so there is nothing to lose. Any key press or host command
  restores it immediately.

---

## Boot

On power-up, before the first host command: `close()`, then `open()`, then two
`blink()`s, roughly one second total, then settle into `calm`.

Cheap, and it confirms the panel and I2C bus are alive before any host is
involved — which is exactly the moment you want that confirmation.

---

## Implementation notes

### Firmware (`v0/firmware/open_deck/open_deck.ino`)

- Replace the `PixieState` enum with the four states plus `offline`
- Add `LIST` parsing and a renderer that draws pre-formatted rows verbatim
- Add a `lastHostCommand` timestamp and the 5s/15s watchdogs
- Add the boot animation
- `FACE` replaces `STATE`

All rendering stays on the core-0 render task. Nothing here may run on the
input loop: a full framebuffer flush blocks ~29.5ms and would drop encoder
detents again.

### Host (`v0/bridge/opendeck/`)

- `presence.py` — collapse to four states, delete `ACTIVE_LINGER` and `ASLEEP`
- `face.py` — `FACE`/`LIST`/`TOAST`; add the 2s keepalive
- New `panes.py` — builds the whole list payload: labels, markers, flags,
  windowing, sanitisation, truncation
- `controller.py` — encoder turn and `summon` push a `LIST`; keepalive on the
  refresh tick

### Tests

Roughly 15 additions, all offline:

- Label mapping, including the version-string → `claude` case
- `|` and whitespace sanitisation
- Windowing keeps the active pane visible past 5 panes
- Empty session renders `(empty)`
- Four-state collapse, and `done` still not latching
- Keepalive is emitted on an unchanged state

---

## Risks

**The list is another thing to render, on a panel where a flush costs 29.5ms.**
It is static once drawn, so like the toast it is drawn and flushed once rather
than every frame. Cost is one flush per glance.

**`offline` could flap** if the host stalls briefly. The 5s threshold is 2.5×
the keepalive interval, which tolerates one missed tick.

**Claude Code's process name may change form.** The label rule matches both the
binary name and the version-string shape, so a change to either alone still
resolves.

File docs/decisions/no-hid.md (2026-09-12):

# The deck is not a keyboard

**Decided:** 2026-09-12 · **Status:** settled

Open Deck does not enumerate as a USB HID device and never sends keystrokes.
It speaks a line protocol over USB CDC serial; a host bridge decides what its
events mean.

This has now been proposed, built, and removed **twice**. This note exists so
it is not proposed a third time.

## Why it keeps getting proposed

The bridge used to need an install: a venv and `pyserial`, on Python 3.11 when
macOS ships 3.9. Plugging the deck into a second Mac meant a setup ritual, and
"just make it a keyboard" removes that ritual completely. The reasoning is
sound right up to the point where you ask what a keystroke can address.

## Why it is wrong

**A keyboard has no addressing.** `tmux send-keys -t fox:1.2` names the pane it
talks to. HID names nothing — it types into whatever holds focus, which is a
property of the window server, not of the device. The deck cannot read focus,
so it cannot know whether its keystrokes are landing on tmux, a browser, or a
text field.

The product's whole premise is *which agent needs me, act on that agent*. That
is an addressing problem. A transport that cannot address cannot implement it.

**Every mitigation is a patch on that same flaw**, and they were all tried:

| Mitigation | Why it failed |
|---|---|
| `F13`–`F19`, harmless unbound keycodes | Needed `.tmux.conf` on every machine, which is the install step HID was meant to remove. The bare tier was then three keystrokes you already had. |
| tmux command prompt (`C-b :`), needs no config | Types ~25 characters. Sent `:select-pane -t :.+` into a live Claude Code session. |
| Built-in prefixed keys (`C-b o`), 2 keystrokes | Smaller blast radius, same flaw. An encoder emits dozens of events: `o;;ooo;;;ooo`. |
| Default off, armed by a deliberate chord | A device whose headline feature must be switched on, and which is unsafe once it is. |

Making each misfire smaller was the wrong axis entirely. The fix is a device
that cannot type.

## What replaced it

The reason HID looked necessary — the host install — was removed directly:

- **`pyserial` deleted.** `opendeck/serialport.py` does 8N1 raw termios in
  ~100 lines. The bridge now has zero third-party dependencies.
- **Python floor lowered to 3.9**, the version macOS ships, via two shims in
  `opendeck/compat.py`.

So the install is now `./open-deck`, on any Mac, with nothing installed —
which is what HID was for.

## The honest trade

The deck does nothing until the bridge runs. That is a real cost and it is not
hidden: no bridge, no function.

It buys pane-level addressing, a display that reports agent state the device
cannot observe alone, and a device that is physically incapable of typing into
the wrong window. Stream Deck, Loupedeck, and every MIDI control surface make
the same trade. A control surface is not a keyboard.

## If you are about to propose it again

Answer this first: **how does a keystroke reach a specific tmux pane when the
user is looking at a browser?** Every previous attempt failed on that question,
and it has no answer within HID. If the goal is reducing install friction, the
bridge already installs in one command with no dependencies — reduce it further
there, not by changing what the device is.

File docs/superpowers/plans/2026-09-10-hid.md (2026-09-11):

# HID Implementation Plan

> **For agentic workers:** REQUIRED SUB-SKILL: Use superpowers:subagent-driven-development (recommended) or superpowers:executing-plans to implement this plan task-by-task. Steps use checkbox (`- [ ]`) syntax for tracking.

**Goal:** Make the deck work as a plain USB keyboard on a machine with nothing installed, while keeping the full tmux experience where the daemon runs.

**Architecture:** The ESP32-S3 enumerates as a composite HID+CDC device. Keys emit serial events as they do today; when no host has been talking, they *also* send real keystrokes. Arbitration reuses the existing offline watchdog rather than adding state, so a keypress never produces two actions.

**Tech Stack:** Arduino ESP32 core 3.3.11, `USBHIDKeyboard` (TinyUSB), tmux.

**Spec:** `docs/superpowers/specs/2026-09-10-hid-design.md`

## Global Constraints

- **Build FQBN is `esp32:esp32:XIAO_ESP32S3:USBMode=default`** — not the bare board name. The default (`hwcdc`) uses the hardware USB-Serial/JTAG peripheral, which cannot do HID at all. Every compile and upload command in this plan must carry it.
- **Rendering runs on core 0 (`renderTask`); input runs on core 1 (`loop()`).** A full SH1106 flush blocks ~29.5ms. Display work reachable from `loop()` drops encoder detents.
- **Firmware serial writes go through `emit()`**, never raw `Serial.print`/`printf`. USB CDC blocks once its TX ring fills with no host reading.
- Cross-core shared state goes through `portMUX_TYPE faceMux`, or is a single naturally-aligned `volatile` word.
- Do not change the key matrix, encoder decoding, or the `EVT`/`HB` output.
- Commit after each task. Do not push; the controller handles that.

## Phase 1 is already done

The USB mode switch was verified on hardware before this plan was written:

- Flashed with `USBMode=default`; the daemon connected and drove the face.
- **The serial port was renamed**: `/dev/cu.usbmodem11301` → `/dev/cu.usbmodemE072A1F956A81`. TinyUSB enumerates using the MAC-derived serial rather than the JTAG naming.
- `transport.discover_port()` globs `/dev/cu.usbmodem*`, so autodetect still works — but **anyone pinning `serial_port` in config or `--port` on the command line will break.** Task 3 documents this.

---

### Task 1: HID keymap and arbitration

**Files:**
- Modify: `v0/firmware/open_deck/open_deck.ino`

**Interfaces:**
- Consumes: existing `lastHostCommand`, `OFFLINE_AFTER_MS`, `KEY_NAMES`, `emit()`
- Produces: `hidArmed()` predicate; HID keystrokes on the key-release path

There is no host test harness for firmware. Verification is compile plus driving the device by hand, as in Step 6.

- [ ] **Step 1: Add the HID includes and object**

At the top of the file, after the existing includes:

```cpp
#include <USB.h>
#include <USBHIDKeyboard.h>
```

After the `RoboEyes` declaration:

```cpp
USBHIDKeyboard Keyboard;
```

- [ ] **Step 2: Add the arbitration state**

Beside `lastHostCommand`:

```cpp
// HID fires only when no daemon is listening, so a keypress never produces
// two actions. The thresholds are deliberately asymmetric: a machine that has
// never seen a host is a bare machine and should get working keys quickly,
// while a host that spoke and went quiet is probably mid-hiccup - a slow tmux
// call or a daemon restart - and typing Escape into whatever window happens to
// be focused would be worse than doing nothing.
volatile bool hostEverSeen = false;
const unsigned long HID_ARM_COLD_MS = OFFLINE_AFTER_MS;   // never seen a host
const unsigned long HID_ARM_WARM_MS = 15000;              // seen, then lost

bool hidArmed() {
  unsigned long since = millis() - lastHostCommand;
  if (!lastHostCommand) return true;
  return since > (hostEverSeen ? HID_ARM_WARM_MS : HID_ARM_COLD_MS);
}
```

Set the flag where the host is first heard — in `handleCommand`, beside the existing `lastHostCommand = millis();`:

```cpp
  hostEverSeen = true;
```

- [ ] **Step 3: Add the keymap**

Beside `KEY_NAMES`, indexed identically so the two arrays cannot drift:

```cpp
// Sent only when hidArmed(). F13-F24 are real HID keycodes that essentially
// nothing binds by default, so they are safe to send blind on an unknown
// machine: inert there, bindable in .tmux.conf where the user wants more.
const uint8_t HID_KEYS[8] = {
  KEY_F17,       // KEY_TERM
  ' ',           // KEY_MIC   - voice-mode toggle
  KEY_F13,       // KEY_AGENT1
  KEY_F16,       // KEY_AGENT4
  KEY_RETURN,    // KEY_ENTER
  KEY_ESC,       // KEY_CANCEL
  KEY_F15,       // KEY_AGENT3
  KEY_F14,       // KEY_AGENT2
};
```

- [ ] **Step 4: Send HID on key release**

In `scanMatrix`, in the branch that emits `UP`:

```cpp
        } else {
          emit(String("EVT ") + KEY_NAMES[idx] + " UP");
          // Release, not press: a tap should type once, and the host's own
          // tap/hold resolution also happens on release.
          if (hidArmed()) Keyboard.write(HID_KEYS[idx]);
        }
```

- [ ] **Step 5: Send HID for the encoder**

In `loop()`, where the encoder event is emitted:

```cpp
  if (dir != 0) {
    emit(String("EVT ENCODER ") + (dir > 0 ? "+1" : "-1"));
    if (hidArmed()) Keyboard.write(dir > 0 ? KEY_F19 : KEY_F18);
  }
```

- [ ] **Step 6: Start USB in setup()**

Before `xTaskCreatePinnedToCore`, after the display is initialised:

```cpp
  Keyboard.begin();
  USB.begin();
```

- [ ] **Step 7: Compile**

Run: `arduino-cli compile --fqbn "esp32:esp32:XIAO_ESP32S3:USBMode=default" v0/firmware/open_deck`
Expected: success.

- [ ] **Step 8: Commit**

```bash
git add v0/firmware/open_deck/open_deck.ino
git commit -m "feat: send HID keystrokes when no daemon is listening"
```

---

### Task 2: tmux bindings for the zero-install tier

**Files:**
- Create: `v0/bridge/scripts/opendeck.tmux.conf`

- [ ] **Step 1: Write the config**

```tmux
# Open Deck - bindings for the install-free tier.
#
# With these and no daemon at all, the deck's project keys switch tmux
# sessions and the encoder moves between windows. Source it from ~/.tmux.conf:
#
#     source-file /path/to/opendeck.tmux.conf
#
# The deck sends F13-F19 only while no daemon is listening. With the daemon
# running it talks over serial instead, and these bindings stay dormant.
#
# Rename the session targets to match your own.

bind-key -n F13 switch-client -t fox
bind-key -n F14 switch-client -t owl
bind-key -n F15 switch-client -t cat
bind-key -n F16 switch-client -t pnda

# TERM: a new window in the current session.
bind-key -n F17 new-window

# Encoder. This tier moves between WINDOWS, not panes - tmux has no built-in
# "next pane across the whole session", which is what the daemon provides.
bind-key -n F18 previous-window
bind-key -n F19 next-window
```

- [ ] **Step 2: Verify it parses**

Run: `tmux -f v0/bridge/scripts/opendeck.tmux.conf new-session -d -s conftest \; kill-session -t conftest`
Expected: no error output. A syntax error in a tmux config fails loudly here.

- [ ] **Step 3: Commit**

```bash
git add v0/bridge/scripts/opendeck.tmux.conf
git commit -m "feat: tmux bindings for the install-free tier"
```

---

### Task 3: Documentation

**Files:**
- Modify: `README.md`
- Modify: `v0/README.md`

- [ ] **Step 1: Add the tiers table to `README.md`**

In the "What it does" area, after the existing description:

```markdown
## Three tiers

The deck degrades rather than dying when its daemon isn't there.

| Tier | Needs | Gets |
|---|---|---|
| **Bare** | nothing | keys send real keystrokes — Enter, Escape, Space, F13-F19 |
| **+ tmux** | `source-file opendeck.tmux.conf` | session switching and window cycling |
| **Full** | the daemon | pane-level navigation, Pixie, the pane list |

HID fires only while no daemon is listening, so a keypress never does two
things. It types into the **focused window** — it cannot target a pane the way
the daemon's `tmux send-keys` does, so the bare tier interrupts what you are
looking at rather than a specific agent.
```

- [ ] **Step 2: Add the build and recovery notes to `v0/README.md`**

In the flashing section, replace the `arduino-cli` commands with the pinned FQBN and add the warning:

```markdown
```bash
arduino-cli compile --fqbn "esp32:esp32:XIAO_ESP32S3:USBMode=default" firmware/open_deck
arduino-cli upload  --fqbn "esp32:esp32:XIAO_ESP32S3:USBMode=default" -p /dev/cu.usbmodemXXXX firmware/open_deck
```

> **The `USBMode=default` suffix is required.** The board's default build mode
> (`hwcdc`) uses the hardware USB-Serial/JTAG peripheral, which cannot do HID
> at all. Build without the suffix and you get a working deck with no HID and
> no symptom until you plug it into another machine.
```

Add to the hard-won notes:

```markdown
- **Switching to `USBMode=default` renames the serial port.** TinyUSB
  enumerates using the MAC-derived serial (`/dev/cu.usbmodemE072A1F956A81`)
  rather than the JTAG naming (`/dev/cu.usbmodem11301`). Autodetect globs
  `/dev/cu.usbmodem*` so it still works, but a pinned `serial_port` in
  `config.json` or `--port` on the command line will break.
- **Under TinyUSB the firmware creates the serial port**, so a build that fails
  to bring up USB makes the port vanish. Recovery: unplug, hold **BOOT**, plug
  in, keep holding ~2s, release, then flash normally — the bootloader's port is
  independent of the app firmware.
```

- [ ] **Step 3: Commit**

```bash
git add README.md v0/README.md
git commit -m "docs: HID tiers, pinned FQBN, and BOOT recovery"
```

---

### Task 4: Hardware verification

Controller-owned; needs the physical device and a human watching. Not for a subagent.

- [ ] **Step 1: Flash**

```bash
pkill -f opendeck
arduino-cli upload --fqbn "esp32:esp32:XIAO_ESP32S3:USBMode=default" -p $(ls /dev/cu.usbmodem*) v0/firmware/open_deck
```

- [ ] **Step 2: Confirm HID arms with no daemon**

With the daemon stopped, wait ~6s, then focus a text editor and press ENTER, X and MIC. Expect a newline, an escape, and a space. Confirm the agent keys produce nothing visible (F13-F16 are inert unbound).

- [ ] **Step 3: Confirm HID disarms with the daemon running**

Start the daemon, focus a text editor, press ENTER. Expect **nothing typed** — the daemon owns the keys and delivers via tmux instead.

- [ ] **Step 4: Confirm the warm threshold**

With the daemon running, kill it and immediately press ENTER. Expect nothing typed for ~15s, then HID arms. This is the guard against a stalled daemon typing into a browser.

- [ ] **Step 5: Confirm the tmux tier**

`source-file` the config, stop the daemon, wait for HID to arm, press an agent key. Expect a session switch with no daemon involved.

---

## Self-Review

**Spec coverage:**

| Spec section | Task |
|---|---|
| `USBMode=default` switch | Phase 1 (done before this plan) |
| HID keymap incl. F13-F19 | 1 |
| Arbitration with asymmetric thresholds | 1 |
| `hostEverSeen` state | 1 |
| tmux bindings for the bare tier | 2 |
| Tiers table, HID limitations | 3 |
| Pinned FQBN, BOOT recovery | 3 |
| Port-rename warning | 3 (found in Phase 1) |
| Second-machine verification | 4, and a real second Mac afterwards |

**Placeholder scan:** none.

**Type consistency:** `hidArmed()` is defined in Task 1 Step 2 and called in
Steps 4 and 5. `HID_KEYS` is defined in Step 3 and indexed by the same `idx`
that indexes `KEY_NAMES`, which is what keeps the two arrays aligned.

**Known gap:** Task 4 Step 5 verifies the tmux tier on *this* Mac, where the
daemon exists. The actual claim — that the deck works on a machine with nothing
installed — can only be proven on a second machine, and that is a manual step
after this plan.

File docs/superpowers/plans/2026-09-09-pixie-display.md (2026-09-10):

# Pixie Display Implementation Plan

> **For agentic workers:** REQUIRED SUB-SKILL: Use superpowers:subagent-driven-development (recommended) or superpowers:executing-plans to implement this plan task-by-task. Steps use checkbox (`- [ ]`) syntax for tracking.

**Goal:** Make the Open Deck OLED useful by resting on Pixie's face, revealing a pane list while you interact, and never lying about whether it is live.

**Architecture:** The display is split by *time*, not screen area: an ambient face, a glance layer (pane list) that decays after 1.2s, and alerts. The host formats and windows the list; the firmware is a dumb renderer. All rendering stays on the ESP32's core 0 — the input loop on core 1 must never block.

**Tech Stack:** Python 3.11+ (stdlib + pyserial), Arduino/ESP32-S3, FluxGarage RoboEyes, Adafruit SH110X, tmux.

**Spec:** `docs/superpowers/specs/2026-09-09-pixie-display-design.md`

## Global Constraints

- Python 3.11+; stdlib plus `pyserial` only. No new dependencies.
- Tests must run with no hardware, no tmux, and no terminal app. Everything goes through the fakes in `v0/bridge/tests/fakes.py`.
- Run tests with `v0/bridge/tests/run_tests.sh` (it finds the repo `.venv` itself).
- Display is 128×64 mono = **21 characters × 6 usable rows** at the default font.
- Wire protocol is newline-delimited ASCII at 115200 baud. `|` is the `LIST` delimiter and must never appear inside a field.
- Firmware rendering runs only on the core-0 render task. A full framebuffer flush blocks ~29.5ms; putting it on the input loop drops encoder detents.
- Serial writes from firmware use `emit()`, which drops rather than blocks when the host is not reading.
- Commit after each task with a `feat:`/`refactor:` prefixed message.

---

### Task 1: Collapse presence to four states

**Files:**
- Modify: `v0/bridge/opendeck/presence.py`
- Modify: `v0/bridge/tests/test_presence.py`

**Interfaces:**
- Consumes: `SlotTable`, `Tmux`, `is_agent`, `is_busy` (all existing)
- Produces: `State.ALERT`, `State.BUSY`, `State.DONE`, `State.CALM` (StrEnum values `"alert"`, `"busy"`, `"done"`, `"calm"`); `Snapshot(state, attention_session=None)`; `PresenceMonitor.evaluate(now=None) -> Snapshot`. `PresenceMonitor.note_input()` is removed.

- [ ] **Step 1: Rewrite the failing tests**

Replace the whole `class TestPresence` body in `v0/bridge/tests/test_presence.py` with:

```python
class TestPresence(unittest.TestCase):
    def test_no_sessions_is_calm(self):
        mon, _ = monitor([], client=False)
        self.assertEqual(mon.evaluate(0.0).state, State.CALM)

    def test_idle_shell_is_calm(self):
        mon, _ = monitor(["webapp"], panes={"webapp": [pane(command="zsh", pane_active=True)]})
        self.assertEqual(mon.evaluate(100.0).state, State.CALM)

    def test_running_agent_is_busy(self):
        mon, _ = monitor(
            ["webapp"],
            panes={"webapp": [pane(command="claude", window_active=True, pane_active=True)]},
        )
        self.assertEqual(mon.evaluate(100.0).state, State.BUSY)

    def test_activity_elsewhere_takes_priority_over_busy(self):
        mon, _ = monitor(
            ["webapp", "api"],
            panes={"webapp": [pane(command="claude", pane_active=True)]},
            windows={"api": [window(activity=True)]},
        )
        snapshot = mon.evaluate(100.0)
        self.assertEqual(snapshot.state, State.ALERT)
        self.assertEqual(snapshot.attention_session, "api")

    def test_a_bell_also_raises_alert(self):
        mon, _ = monitor(
            ["webapp", "api"],
            panes={"webapp": [pane(command="zsh")]},
            windows={"api": [window(bell=True)]},
        )
        self.assertEqual(mon.evaluate(100.0).state, State.ALERT)

    def test_activity_in_the_current_session_is_not_an_alert(self):
        mon, _ = monitor(
            ["webapp"],
            panes={"webapp": [pane(command="zsh")]},
            windows={"webapp": [window(activity=True)]},
        )
        self.assertNotEqual(mon.evaluate(100.0).state, State.ALERT)

    def test_agent_disappearing_reports_done_once(self):
        tmux = FakeTmux(
            sessions=["webapp"],
            panes={"webapp": [pane(command="claude", pane_active=True)]},
        )
        slots = SlotTable(tmux)
        slots.refresh()
        mon = PresenceMonitor(tmux, slots)

        self.assertEqual(mon.evaluate(10.0).state, State.BUSY)
        tmux._panes = {"webapp": [pane(command="zsh", pane_active=True)]}
        self.assertEqual(mon.evaluate(11.0).state, State.DONE)
        # DONE must not latch, or the face would stay happy forever.
        self.assertEqual(mon.evaluate(12.0).state, State.CALM)

    def test_a_running_program_counts_as_busy(self):
        mon, _ = monitor(["webapp"], panes={"webapp": [pane(command="vim")]})
        self.assertEqual(mon.evaluate(100.0).state, State.BUSY)

    def test_shells_are_never_mistaken_for_agents(self):
        for shell in ("zsh", "bash", "fish", "-zsh"):
            with self.subTest(shell=shell):
                mon, _ = monitor(["webapp"], panes={"webapp": [pane(command=shell)]})
                self.assertEqual(mon.evaluate(100.0).state, State.CALM)

    def test_claude_code_version_string_is_recognised_as_an_agent(self):
        from opendeck.presence import is_agent

        for version in ("2.1.261", "2.1.259", "1.0.0"):
            with self.subTest(version=version):
                self.assertTrue(is_agent(version))

    def test_agent_detection_rejects_shells_and_plain_names(self):
        from opendeck.presence import is_agent

        self.assertFalse(is_agent("zsh"))
        self.assertFalse(is_agent(""))
        self.assertFalse(is_agent("vim"))

    def test_version_agent_finishing_reports_done(self):
        tmux = FakeTmux(
            sessions=["webapp"], panes={"webapp": [pane(command="2.1.261", pane_active=True)]}
        )
        slots = SlotTable(tmux)
        slots.refresh()
        mon = PresenceMonitor(tmux, slots)
        self.assertEqual(mon.evaluate(10.0).state, State.BUSY)
        tmux._panes = {"webapp": [pane(command="zsh", pane_active=True)]}
        self.assertEqual(mon.evaluate(11.0).state, State.DONE)

    def test_state_values_are_the_wire_names(self):
        self.assertEqual(
            {State.ALERT, State.BUSY, State.DONE, State.CALM},
            {"alert", "busy", "done", "calm"},
        )
```

- [ ] **Step 2: Run the tests to verify they fail**

Run: `v0/bridge/tests/run_tests.sh -k TestPresence`
Expected: FAIL with `AttributeError: ALERT` (the enum member does not exist yet).

- [ ] **Step 3: Rewrite the state enum and evaluate()**

In `v0/bridge/opendeck/presence.py`, replace the `ACTIVE_LINGER`/`SLEEP_AFTER` constants and the `State` class with:

```python
class State(StrEnum):
    ALERT = "alert"
    BUSY = "busy"
    DONE = "done"
    CALM = "calm"
```

Delete `note_input`, the `_last_input` attribute, and its assignment in `__init__`. Replace `evaluate` with:

```python
    def evaluate(self, now: float | None = None) -> Snapshot:
        current = self._slots.current_session()
        if current is None:
            return Snapshot(State.CALM)

        # 1. Something wants attention in a session you are not looking at.
        for session in self._slots.slots:
            if not session or session == current:
                continue
            if any(w.activity or w.bell for w in self._tmux.windows(session)):
                return Snapshot(State.ALERT, attention_session=session)

        panes = self._tmux.panes(current)
        agents_here = {p.target for p in panes if is_agent(p.command)}
        busy_here = any(is_busy(p.command) for p in panes)
        key = f"{current}:"
        previously = {t for t in self._agent_seen if t.startswith(key)}
        currently = {f"{key}{t}" for t in agents_here}

        # 2. An agent that was running here has stopped.
        finished = previously - currently
        self._agent_seen = (self._agent_seen - previously) | currently
        if finished:
            return Snapshot(State.DONE)

        # 3. Anything running here is enough to look busy; DONE is tracked
        #    only for agents so quitting an editor does not celebrate.
        if agents_here or busy_here:
            return Snapshot(State.BUSY)

        return Snapshot(State.CALM)
```

Keep the `now` parameter: callers pass it and dropping it would break them.

- [ ] **Step 4: Run the tests to verify they pass**

Run: `v0/bridge/tests/run_tests.sh -k TestPresence`
Expected: PASS.

- [ ] **Step 5: Fix the callers**

`grep -rn "note_input\|State.ATTENTION\|State.WORKING\|State.IDLE\|State.ACTIVE\|State.ASLEEP" v0/bridge/` and update each hit:
- In `opendeck/controller.py`, delete both `self._presence.note_input(now)` calls and change `State.ATTENTION` to `State.ALERT`.
- In `tests/test_controller.py`, change `State.ATTENTION` to `State.ALERT` and `State.WORKING` to `State.BUSY`.

- [ ] **Step 6: Run the whole suite**

Run: `v0/bridge/tests/run_tests.sh`
Expected: PASS, no errors.

- [ ] **Step 7: Commit**

```bash
git add v0/bridge/opendeck/presence.py v0/bridge/opendeck/controller.py v0/bridge/tests/
git commit -m "refactor: collapse presence to four face states"
```

---

### Task 2: Build the pane list payload

**Files:**
- Create: `v0/bridge/opendeck/panes.py`
- Create: `v0/bridge/tests/test_panes.py`

**Interfaces:**
- Consumes: `opendeck.tmux.Pane`, `opendeck.tmux.Window`, `opendeck.presence.is_agent`, `opendeck.tmux.SHELLS`
- Produces: `pane_label(pane: Pane, window: Window | None) -> str`; `build_list(title: str, panes: list[Pane], windows: list[Window], max_rows: int = 5) -> str` returning the full `LIST` payload body (title and rows joined by `|`, without the `LIST ` prefix).

- [ ] **Step 1: Write the failing tests**

Create `v0/bridge/tests/test_panes.py`:

```python
import unittest

from fakes import pane, window
from opendeck.panes import build_list, pane_label

class TestPaneLabel(unittest.TestCase):
    def test_prefers_a_deliberate_window_name(self):
        p = pane(command="node")
        w = window(name="claude")
        self.assertEqual(pane_label(p, w), "claude")

    def test_ignores_generic_shell_window_names(self):
        p = pane(command="vim")
        w = window(name="zsh")
        self.assertEqual(pane_label(p, w), "vim")

    def test_claude_version_string_reads_as_claude(self):
        # Claude Code reports its version as the process name.
        self.assertEqual(pane_label(pane(command="2.1.261"), None), "claude")

    def test_falls_back_to_the_command(self):
        self.assertEqual(pane_label(pane(command="npm"), None), "npm")

    def test_empty_command_is_marked_unknown(self):
        self.assertEqual(pane_label(pane(command=""), None), "?")

    def test_delimiter_and_spaces_are_sanitised(self):
        # "|" is the wire delimiter and would corrupt the payload.
        self.assertEqual(pane_label(pane(command="a|b c"), None), "a_b_c")

    def test_label_is_truncated(self):
        label = pane_label(pane(command="x" * 40), None)
        self.assertLessEqual(len(label), 13)

class TestBuildList(unittest.TestCase):
    def test_title_leads_the_payload(self):
        payload = build_list("FOX webapp 1/1", [pane(pane_active=True, window_active=True)], [])
        self.assertTrue(payload.startswith("FOX webapp 1/1|"))

    def test_active_pane_is_marked(self):
        panes = [
            pane(index=0, command="claude"),
            pane(index=1, command="nvim", window_active=True, pane_active=True),
        ]
        rows = build_list("t", panes, []).split("|")[1:]
        self.assertTrue(rows[1].startswith(">"))
        self.assertFalse(rows[0].startswith(">"))

    def test_empty_session_renders_a_placeholder(self):
        self.assertEqual(build_list("t", [], []), "t|(empty)")

    def test_at_most_five_rows(self):
        panes = [pane(index=i, command=f"c{i}") for i in range(9)]
        panes[0] = pane(index=0, command="c0", window_active=True, pane_active=True)
        rows = build_list("t", panes, []).split("|")[1:]
        self.assertEqual(len(rows), 5)

    def test_window_keeps_the_active_pane_visible(self):
        panes = [pane(index=i, command=f"c{i}") for i in range(9)]
        panes[8] = pane(index=8, command="c8", window_active=True, pane_active=True)
        rows = build_list("t", panes, []).split("|")[1:]
        self.assertTrue(any(r.startswith(">") for r in rows))

    def test_activity_flag_is_appended(self):
        panes = [pane(window=0, index=0, command="zsh", window_active=True, pane_active=True)]
        windows = [window(index=0, activity=True)]
        row = build_list("t", panes, windows).split("|")[1]
        self.assertTrue(row.rstrip().endswith("*"))

    def test_bell_flag_beats_activity(self):
        panes = [pane(window=0, index=0, command="zsh", window_active=True, pane_active=True)]
        windows = [window(index=0, activity=True, bell=True)]
        row = build_list("t", panes, windows).split("|")[1]
        self.assertTrue(row.rstrip().endswith("!"))

    def test_no_row_exceeds_the_display_width(self):
        panes = [pane(index=i, command="x" * 30) for i in range(3)]
        for row in build_list("t" * 40, panes, []).split("|"):
            self.assertLessEqual(len(row), 21)

    def test_payload_never_contains_a_stray_delimiter(self):
        panes = [pane(index=0, command="a|b", window_active=True, pane_active=True)]
        payload = build_list("ti|tle", panes, [])
        # One delimiter per row boundary and no more.
        self.assertEqual(payload.count("|"), 1)

if __name__ == "__main__":
    unittest.main()
```

- [ ] **Step 2: Run the tests to verify they fail**

Run: `v0/bridge/tests/run_tests.sh -k test_panes`
Expected: FAIL with `ModuleNotFoundError: No module named 'opendeck.panes'`.

- [ ] **Step 3: Write the implementation**

Create `v0/bridge/opendeck/panes.py`:

```python
"""Formats the pane list the deck displays.

The host owns every formatting rule - windowing, markers, flags, truncation -
so the firmware stays a dumb renderer and all of this stays testable here.
"""

from __future__ import annotations

from .presence import is_agent
from .tmux import SHELLS, Pane, Window

DISPLAY_WIDTH = 21
MAX_ROWS = 5
LABEL_WIDTH = 13
EMPTY_ROW = "(empty)"

_GENERIC_NAMES = frozenset({"zsh", "bash", "sh", "fish"})
_AGENT_LABEL = "claude"

def _sanitise(text: str) -> str:
    """Strip anything that would corrupt the wire payload."""
    return "".join("_" if ch in "| \t" else ch for ch in text)

def pane_label(pane: Pane, window: Window | None) -> str:
    if window is not None and window.name and window.name not in _GENERIC_NAMES:
        label = window.name
    elif is_agent(pane.command) and pane.command not in SHELLS:
        # Claude Code reports its version string as the process name, so the
        # raw command is useless as a label even though it is a real agent.
        label = pane.command if pane.command.isalpha() else _AGENT_LABEL
    else:
        label = pane.command or "?"
    return _sanitise(label)[:LABEL_WIDTH]

def _flag(pane: Pane, windows: list[Window]) -> str:
    for w in windows:
        if w.index == pane.window:
            return w.flag.strip()
    return ""

def _window_rows(panes: list[Pane], max_rows: int) -> list[Pane]:
    """Slice the list so the active pane is always visible."""
    if len(panes) <= max_rows:
        return panes
    active = next((i for i, p in enumerate(panes) if p.active), 0)
    first = max(0, min(active - max_rows // 2, len(panes) - max_rows))
    return panes[first : first + max_rows]

def build_list(
    title: str,
    panes: list[Pane],
    windows: list[Window],
    max_rows: int = MAX_ROWS,
) -> str:
    rows = []
    for pane in _window_rows(panes, max_rows):
        marker = ">" if pane.active else " "
        flag = _flag(pane, windows)
        row = f"{marker}{pane.index:<2}{pane_label(pane, None)}"
        if flag:
            row = f"{row} {flag}"
        rows.append(row[:DISPLAY_WIDTH])
    if not rows:
        rows = [EMPTY_ROW]
    return "|".join([_sanitise(title)[:DISPLAY_WIDTH], *rows])
```

- [ ] **Step 4: Run the tests to verify they pass**

Run: `v0/bridge/tests/run_tests.sh -k test_panes`
Expected: PASS.

If `test_prefers_a_deliberate_window_name` fails, note that `build_list` passes `None` for the window while `pane_label` is tested directly with one — this is intentional; only Task 4 wires real windows through.

- [ ] **Step 5: Commit**

```bash
git add v0/bridge/opendeck/panes.py v0/bridge/tests/test_panes.py
git commit -m "feat: build the pane list payload host-side"
```

---

### Task 3: Teach Face the new protocol

**Files:**
- Modify: `v0/bridge/opendeck/face.py`
- Create: `v0/bridge/tests/test_face.py`

**Interfaces:**
- Consumes: `SerialTransport.send`, `Snapshot`, `State` (four-state version from Task 1)
- Produces: `Face.apply(snapshot) -> bool` sending `FACE <state>`; `Face.toast(text)`; `Face.show_list(payload)` sending `LIST <payload>`; `Face.keepalive()` re-sending the last `FACE` unconditionally; `Face.reset()`.

- [ ] **Step 1: Write the failing tests**

Create `v0/bridge/tests/test_face.py`:

```python
import unittest

from opendeck.face import Face
from opendeck.presence import Snapshot, State

class FakeTransport:
    def __init__(self):
        self.sent = []

    def send(self, line):
        self.sent.append(line)
        return True

class TestFace(unittest.TestCase):
    def setUp(self):
        self.transport = FakeTransport()
        self.face = Face(self.transport)

    def test_apply_sends_the_wire_name(self):
        self.assertTrue(self.face.apply(Snapshot(State.BUSY)))
        self.assertEqual(self.transport.sent, ["FACE busy"])

    def test_unchanged_state_is_not_resent(self):
        self.face.apply(Snapshot(State.CALM))
        self.transport.sent.clear()
        self.assertFalse(self.face.apply(Snapshot(State.CALM)))
        self.assertEqual(self.transport.sent, [])

    def test_reset_forces_a_repaint(self):
        self.face.apply(Snapshot(State.CALM))
        self.face.reset()
        self.assertTrue(self.face.apply(Snapshot(State.CALM)))

    def test_keepalive_resends_even_when_unchanged(self):
        # The device uses any received command as a liveness tick, so this
        # must go out regardless of whether the state moved.
        self.face.apply(Snapshot(State.BUSY))
        self.transport.sent.clear()
        self.face.keepalive()
        self.assertEqual(self.transport.sent, ["FACE busy"])

    def test_keepalive_before_any_state_sends_calm(self):
        self.face.keepalive()
        self.assertEqual(self.transport.sent, ["FACE calm"])

    def test_toast_is_truncated_to_the_display_width(self):
        self.face.toast("x" * 40)
        self.assertEqual(len(self.transport.sent[0]), len("TOAST ") + 21)

    def test_show_list_sends_the_payload(self):
        self.face.show_list("FOX webapp|>0 claude")
        self.assertEqual(self.transport.sent, ["LIST FOX webapp|>0 claude"])

if __name__ == "__main__":
    unittest.main()
```

- [ ] **Step 2: Run the tests to verify they fail**

Run: `v0/bridge/tests/run_tests.sh -k test_face`
Expected: FAIL — `AssertionError: ['STATE busy'] != ['FACE busy']`.

- [ ] **Step 3: Write the implementation**

Replace the body of `Face` in `v0/bridge/opendeck/face.py`:

```python
class Face:
    def __init__(self, transport: SerialTransport) -> None:
        self._transport = transport
        self._state: State | None = None

    def reset(self) -> None:
        """Forget the pushed state so the next update repaints."""
        self._state = None

    def apply(self, snapshot: Snapshot) -> bool:
        """Push the expression, returning True if it changed."""
        if snapshot.state is self._state:
            return False
        self._state = snapshot.state
        self._transport.send(f"FACE {snapshot.state}")
        log.debug("face -> %s", snapshot.state)
        return True

    def keepalive(self) -> None:
        """Re-send the current face unconditionally.

        The device treats any received command as proof the host is alive and
        falls back to an offline face without one. The firmware early-returns
        on an unchanged state, so this restarts no animation.
        """
        self._transport.send(f"FACE {self._state or State.CALM}")

    def toast(self, text: str) -> None:
        text = text[:TOAST_MAX]
        log.info("toast: %s", text)
        self._transport.send(f"TOAST {text}")

    def show_list(self, payload: str) -> None:
        self._transport.send(f"LIST {payload}")
```

- [ ] **Step 4: Run the tests to verify they pass**

Run: `v0/bridge/tests/run_tests.sh -k test_face`
Expected: PASS.

- [ ] **Step 5: Commit**

```bash
git add v0/bridge/opendeck/face.py v0/bridge/tests/test_face.py
git commit -m "feat: FACE/LIST protocol and host keepalive"
```

---

### Task 4: Show the list on encoder turn and summon

**Files:**
- Modify: `v0/bridge/opendeck/controller.py`
- Modify: `v0/bridge/tests/test_controller.py`

**Interfaces:**
- Consumes: `panes.build_list`, `Face.show_list`, `Face.keepalive`, `SlotTable`, `Tmux.panes`, `Tmux.windows`
- Produces: `Controller._push_pane_list()` — builds and sends the current session's list

- [ ] **Step 1: Write the failing tests**

Append to `v0/bridge/tests/test_controller.py`:

```python
class TestPaneListGlance(unittest.TestCase):
    def _controller(self):
        from fakes import pane

        tmux = FakeTmux(
            sessions=["webapp"],
            panes={"webapp": [
                pane(index=0, command="claude", window_active=True, pane_active=True),
                pane(index=1, command="nvim"),
            ]},
        )
        transport = FakeTransport()
        ctrl = Controller(Config(), transport, tmux, FakeTerminal())
        ctrl.slots.refresh()
        return ctrl, transport

    def test_encoder_pushes_the_pane_list(self):
        ctrl, transport = self._controller()
        ctrl.handle_encoder(1)
        lists = [m for m in transport.sent if m.startswith("LIST ")]
        self.assertEqual(len(lists), 1)
        self.assertIn("claude", lists[0])

    def test_list_title_names_the_slot_and_session(self):
        ctrl, transport = self._controller()
        ctrl.handle_encoder(1)
        title = next(m for m in transport.sent if m.startswith("LIST ")).split("|")[0]
        self.assertIn("FOX", title)
        self.assertIn("webapp", title)

    def test_summon_pushes_the_list_not_a_toast(self):
        ctrl, transport = self._controller()
        ctrl._announce("summon", {"slot": 0})
        self.assertTrue(any(m.startswith("LIST ") for m in transport.sent))
        self.assertFalse(any(m.startswith("TOAST ") for m in transport.sent))

    def test_interrupt_still_toasts(self):
        ctrl, transport = self._controller()
        ctrl._announce("interrupt", {"slot": 0})
        self.assertIn("TOAST FOX interrupted", transport.sent)
```

- [ ] **Step 2: Run the tests to verify they fail**

Run: `v0/bridge/tests/run_tests.sh -k TestPaneListGlance`
Expected: FAIL — no `LIST` messages are sent.

- [ ] **Step 3: Write the implementation**

In `v0/bridge/opendeck/controller.py`, add the import:

```python
from . import actions, panes
```

Add the method:

```python
    def _push_pane_list(self) -> None:
        session = self._slots.current_session()
        if session is None:
            return
        slot = self._slots.slot_of(session)
        label = self._slots.label(slot) if slot is not None else "--"
        pane_list = self._context.tmux.panes(session)
        position = next((i + 1 for i, p in enumerate(pane_list) if p.active), 0)
        title = f"{label} {session} {position}/{len(pane_list)}"
        self._face.show_list(
            panes.build_list(title, pane_list, self._context.tmux.windows(session))
        )
```

Replace the `summon` arm of `_announce` — the list names the destination *and* its contents, so the toast is redundant:

```python
            case "summon":
                self._push_pane_list()
```

Change `handle_encoder`:

```python
    def handle_encoder(self, delta: int) -> None:
        actions.cycle_pane(delta)(self._context)
        self._push_pane_list()
```

- [ ] **Step 4: Run the tests to verify they pass**

Run: `v0/bridge/tests/run_tests.sh -k TestPaneListGlance`
Expected: PASS.

- [ ] **Step 5: Add the keepalive to the refresh tick**

In `run()`, replace the refresh block:

```python
            if now - last_refresh >= REFRESH_INTERVAL:
                self._slots.refresh()
                self._announce_presence(self._presence.evaluate(now))
                self._face.keepalive()
                last_refresh = now
```

`REFRESH_INTERVAL` is already 2.0s, which matches the spec's keepalive interval against the device's 5s timeout.

- [ ] **Step 6: Run the whole suite**

Run: `v0/bridge/tests/run_tests.sh`
Expected: PASS.

- [ ] **Step 7: Commit**

```bash
git add v0/bridge/opendeck/controller.py v0/bridge/tests/test_controller.py
git commit -m "feat: reveal the pane list on encoder turn and summon"
```

---

### Task 5: Firmware — FACE, LIST, offline watchdog, boot animation

**Files:**
- Modify: `v0/firmware/open_deck/open_deck.ino`

**Interfaces:**
- Consumes: `FACE <alert|busy|done|calm>`, `TOAST <text>`, `LIST <title>|<row>|…`
- Produces: unchanged device→host events (`EVT`, `HB`)

There is no host test harness for firmware; this task is verified by compiling, flashing, and driving the device over serial by hand.

- [ ] **Step 1: Replace the state enum and its mapping**

Replace the `PixieState` enum and `parseState`:

```cpp
enum PixieState { PX_CALM, PX_BUSY, PX_ALERT, PX_DONE, PX_OFFLINE };
PixieState pixieState = PX_CALM;
```

```cpp
PixieState parseState(const String &name) {
  if (name == "busy")  return PX_BUSY;
  if (name == "alert") return PX_ALERT;
  if (name == "done")  return PX_DONE;
  return PX_CALM;
}
```

Update `applyState`'s switch to the new names, adding the offline arm:

```cpp
  switch (next) {
    case PX_BUSY:
      eyes.setMood(DEFAULT);
      eyes.setCuriosity(true);
      break;
    case PX_ALERT:
      eyes.setMood(ANGRY);
      eyes.setIdleMode(OFF);
      eyes.setPosition(DEFAULT);
      flashTicks = 6;
      flashNext = 0;
      lastPulse = millis();
      break;
    case PX_DONE:
      eyes.setMood(HAPPY);
      eyes.anim_laugh();
      break;
    case PX_OFFLINE:
      eyes.setMood(DEFAULT);
      eyes.setIdleMode(OFF);
      eyes.setAutoblinker(OFF);
      eyes.close();
      break;
    default:
      eyes.setMood(DEFAULT);
      break;
  }
```

Note `applyState` also calls `eyes.open()` in its DEFAULT-settle preamble so a state leaving `PX_OFFLINE` reopens the eyes. Add `eyes.open();` next to the existing `eyes.setMood(DEFAULT);` at the top of `applyState`.

- [ ] **Step 2: Add list state and the renderer**

Beside the toast state, add:

```cpp
#define LIST_ROWS 6
char listRows[LIST_ROWS][22];
int  listCount = 0;
unsigned long listUntil = 0;
bool listDrawn = false;
const unsigned long LIST_MS = 1200;
```

Add the renderer next to `drawToast` (it is likewise drawn once and held, not redrawn per frame):

```cpp
void drawList() {
  display.clearDisplay();
  display.setTextSize(1);
  display.setTextColor(SH110X_WHITE);
  display.setCursor(0, 0);
  display.print(listRows[0]);
  display.drawFastHLine(0, 10, 128, SH110X_WHITE);
  for (int i = 1; i < listCount; i++) {
    display.setCursor(0, 3 + i * 10);
    display.print(listRows[i]);
  }
  display.display();
  listDrawn = true;
}
```

- [ ] **Step 3: Parse LIST and rename STATE to FACE**

In `handleCommand`, replace the `STATE` branch and add `LIST`:

```cpp
  if (cmd == "FACE") {
    sharedState = parseState(nextToken(line, pos));
  } else if (cmd == "TOAST") {
    while (pos < (int)line.length() && line[pos] == ' ') pos++;
    showToast(line.substring(pos));
  } else if (cmd == "LIST") {
    while (pos < (int)line.length() && line[pos] == ' ') pos++;
    showList(line.substring(pos));
  }
```

Add `showList` beside `showToast`, guarded by the same critical section:

```cpp
volatile bool listDirty = false;
char sharedList[LIST_ROWS][22];
int  sharedListCount = 0;

void showList(const String &payload) {
  portENTER_CRITICAL(&faceMux);
  sharedListCount = 0;
  int start = 0;
  while (sharedListCount < LIST_ROWS && start <= (int)payload.length()) {
    int bar = payload.indexOf('|', start);
    String field = (bar < 0) ? payload.substring(start) : payload.substring(start, bar);
    strncpy(sharedList[sharedListCount], field.c_str(), 21);
    sharedList[sharedListCount][21] = '\0';
    sharedListCount++;
    if (bar < 0) break;
    start = bar + 1;
  }
  listDirty = true;
  portEXIT_CRITICAL(&faceMux);
}
```

- [ ] **Step 4: Add the offline watchdog**

Add near the other timing constants:

```cpp
volatile unsigned long lastHostCommand = 0;
const unsigned long OFFLINE_AFTER_MS = 5000;
const unsigned long BLANK_AFTER_MS   = 15UL * 60 * 1000;
bool offlineToastShown = false;
bool panelBlanked = false;
```

Set `lastHostCommand = millis();` as the first line of `handleCommand`.

In `renderTask`, before applying state:

```cpp
    bool hostAlive = lastHostCommand && (millis() - lastHostCommand < OFFLINE_AFTER_MS);
    if (!hostAlive) {
      if (!offlineToastShown) {
        offlineToastShown = true;
        showToast("host offline");
      }
      applyState(PX_OFFLINE);
    } else {
      offlineToastShown = false;
      if (panelBlanked) {
        panelBlanked = false;
        display.clearDisplay();
      }
      applyState(static_cast<PixieState>(sharedState));
    }

    // Nothing live is being shown, so there is nothing to lose by blanking -
    // and a static face would retain on a mono OLED.
    if (!hostAlive && lastHostCommand &&
        millis() - lastHostCommand > BLANK_AFTER_MS) {
      if (!panelBlanked) {
        panelBlanked = true;
        display.clearDisplay();
        display.display();
      }
      vTaskDelay(pdMS_TO_TICKS(200));
      continue;
    }
```

Replace the existing `applyState(static_cast<PixieState>(sharedState));` line with the block above.

- [ ] **Step 5: Render the list ahead of the face**

In `renderTask`, copy the shared list under the mutex alongside the toast copy, then extend the draw selection so the list takes precedence over the face but not the toast:

```cpp
    portENTER_CRITICAL(&faceMux);
    bool newList = listDirty;
    if (newList) {
      for (int i = 0; i < sharedListCount; i++) strncpy(listRows[i], sharedList[i], 22);
      listCount = sharedListCount;
      listDirty = false;
    }
    portEXIT_CRITICAL(&faceMux);
    if (newList) {
      listUntil = millis() + LIST_MS;
      listDrawn = false;
    }
```

```cpp
    if (millis() < toastUntil) {
      if (!toastDrawn) drawToast();
      vTaskDelay(pdMS_TO_TICKS(20));
    } else if (millis() < listUntil) {
      if (!listDrawn) drawList();
      vTaskDelay(pdMS_TO_TICKS(20));
    } else {
      eyes.update();
      vTaskDelay(1);
    }
```

- [ ] **Step 6: Add the boot animation**

At the end of `setup()`, before the `Serial.println`, after the RoboEyes configuration:

```cpp
  // Confirms the panel and I2C bus are alive before any host is involved.
  eyes.close();
  for (int i = 0; i < 12; i++) { eyes.update(); delay(25); }
  eyes.open();
  for (int i = 0; i < 12; i++) { eyes.update(); delay(25); }
  eyes.blink();
  for (int i = 0; i < 20; i++) { eyes.update(); delay(25); }
```

This runs before `xTaskCreatePinnedToCore`, so it is safe to drive the display from `setup()` here.

- [ ] **Step 7: Compile**

Run: `arduino-cli compile --fqbn esp32:esp32:XIAO_ESP32S3 v0/firmware/open_deck`
Expected: success, no errors.

- [ ] **Step 8: Flash and verify by hand**

Stop the daemon first so the port is free: `pkill -f opendeck`

Run: `arduino-cli upload --fqbn esp32:esp32:XIAO_ESP32S3 -p /dev/cu.usbmodem11301 v0/firmware/open_deck`

Then, with no daemon running, confirm each behaviour:
1. On boot the eyes open and blink — panel and I2C are alive.
2. After ~5s with no host, the eyes close and a `host offline` toast appears.
3. `printf 'FACE busy\n' > /dev/cu.usbmodem11301` — the eyes reopen and widen.
4. `printf 'LIST FOX webapp 1/2|>0 claude| 1 nvim\n' > /dev/cu.usbmodem11301` — the list shows for ~1.2s then returns to the face.
5. `printf 'FACE alert\n' > /dev/cu.usbmodem11301` — the screen flashes and the eyes scowl.

- [ ] **Step 9: Commit**

```bash
git add v0/firmware/open_deck/open_deck.ino
git commit -m "feat: FACE/LIST rendering, offline watchdog, boot animation"
```

---

### Task 6: End-to-end verification and docs

**Files:**
- Modify: `docs/protocol-spec.md`
- Modify: `README.md`
- Modify: `v0/README.md`

- [ ] **Step 1: Run the full suite**

Run: `v0/bridge/tests/run_tests.sh`
Expected: PASS, roughly 115 tests.

- [ ] **Step 2: Verify against real hardware**

Start the daemon: `cd v0/bridge && ../.venv/bin/python -m opendeck --command cla -v`

Confirm, in order:
1. Pixie boots, blinks, and settles — no `host offline` toast, because the daemon is up.
2. Turning the encoder shows the pane list, which decays back to the face after ~1.2s.
3. Pressing an animal key shows that session's pane list, not a toast.
4. A Claude Code pane reads `claude`, not `2.1.261`.
5. `tmux send-keys -t <other-session> 'printf "\a"' Enter` — the screen flashes, the eyes scowl, and an `OWL wants you` toast appears.
6. `pkill -f opendeck` — within ~5s the eyes close and `host offline` appears.

- [ ] **Step 3: Update the protocol doc**

In `docs/protocol-spec.md`, replace the "Host → device" section's command list with `FACE`, `TOAST` and `LIST`, documenting: the four wire state names; that `LIST` is one atomic line because a multi-line sequence can be interrupted mid-render; that the host formats and windows rows while the device draws them verbatim; and the 2s keepalive against the 5s offline timeout.

- [ ] **Step 4: Update the READMEs**

In `README.md`, update the "What it does" section to describe the glance layer (the dial reveals the pane list) and the offline state. In `v0/README.md`, add to "Hard-won notes":

```markdown
- **A status display that lies is worse than none.** Without a host keepalive
  the deck happily showed a stale face forever. Any received command is a
  liveness tick; 5s of silence closes Pixie's eyes.
```

- [ ] **Step 5: Commit and push**

```bash
git add -A
git commit -m "docs: FACE/LIST protocol and the glance layer"
git push origin main
```

---

## Self-Review

**Spec coverage:**

| Spec section | Task |
|---|---|
| Four face states | 1 |
| Host → state mapping, `ACTIVE_LINGER`/`ASLEEP` deleted | 1 |
| Pane list layout, markers, flags, `(empty)` | 2 |
| Pane labels incl. version-string → `claude` | 2 |
| Sanitisation and truncation | 2 |
| `FACE`/`TOAST`/`LIST` protocol | 3, 5 |
| Liveness keepalive | 3, 4 |
| Summon shows the list | 4 |
| Glance on encoder turn | 4 |
| Offline watchdog | 5 |
| Burn-in blanking | 5 |
| Boot animation | 5 |
| Docs | 6 |

`calm` burn-in needs no work — idle motion is already on, as the spec notes.

**Placeholder scan:** none. Every code step carries the actual code.

**Type consistency:** `build_list(title, panes, windows, max_rows)` and
`pane_label(pane, window)` are used with those signatures in Tasks 2 and 4.
`Face.show_list(payload)` and `Face.keepalive()` are defined in Task 3 and used
in Task 4. The four `State` members from Task 1 are consumed in Tasks 3 and 4.
Firmware `PX_*` names are consistent between the enum, `parseState`,
`applyState` and `renderTask`.

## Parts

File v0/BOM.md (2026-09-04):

# Open Deck v0 — Bill of Materials

v0 is the **breadboard/hand-wired prototype**: no PCB, no battery, USB-tethered.
Everything here is off-the-shelf and hand-solderable. Total is roughly **$40–60**
depending on what's already in your parts bin.

---

## Electronics

| # | Part | Qty | Notes |
|---|---|---|---|
| 1 | **Seeed Studio XIAO ESP32S3** | 1 | The one used here is the plain S3 (not Sense). Dual-core 240MHz, 8MB flash, 8MB PSRAM. Seeed part **113991114** / LCSC **C20467913** |
| 2 | **1.3" OLED + EC11 rotary encoder combo module** | 1 | I2C, SH1106 driver, 128×64. PCB is **64.9 × 35 mm**. [Amazon B0DMYQHM9J](https://www.amazon.com/dp/B0DMYQHM9J) — see caveat below |
| 3 | **MX-compatible mechanical key switches** | 8 | Any MX-footprint switch. The keycap STLs in `cad/stl/` use an MX cross-stem |
| 4 | **1N4148 diode** | 1 | Only one is used (see "diodes" below) |
| 5 | **Solderless breadboard** | 1 | Half-size is enough |
| 6 | **Jumper wires (M/M and M/F)** | ~24 | 2 per key, 6 for the display module, plus power |
| 7 | **USB-C cable — data, not charge-only** | 1 | Charge-only cables cost hours of debugging here. Verify it enumerates |

### Caveat on the display module

This is a generic unbranded combo board with **no authoritative datasheet**.
Listings from different sellers disagree on dimensions. Confirmed by direct
measurement on the actual unit:

- PCB: 64.9 × 35 mm
- Display: 1.3", 128×64, **SH1106** controller (not SSD1306 — this matters,
  SSD1306 drivers render garbage on it), I2C address `0x3C`
- Encoder: EC11, 20 pulses/rotation, knurled shaft ~15 mm long
- Knob: 15 mm diameter aluminium — **this is the knob, not the shaft**. The
  panel cutout must fit the ~6 mm shaft, not the knob
- **The push-switch on our unit was dead.** Verified with a raw pin-state
  probe: the SW line never moved. Buy assuming you may not get a working
  encoder click — the firmware doesn't use it

If yours has a working push-switch, you have a free extra input and `D7`
could return to it (see the pin map).

### On diodes

A full 8-key matrix normally wants one diode per key to prevent ghosting.
**v0 uses only one** (a leftover from bring-up) and that's fine here:

Ghosting needs three keys held simultaneously in an L-shape across both rows.
A macro pad is pressed one key at a time — there are no chords. The firmware
instead drives rows `OUTPUT_OPEN_DRAIN`, so two keys sharing a column across
rows can't short one row's output into the other, which is the failure that
actually matters electrically.

Add 7 more 1N4148s if you want textbook-correct n-key rollover. v1's PCB will
include them.

---

## 3D-printed parts

Print in PLA. Files in `cad/stl/`.

| Part | Qty | Notes |
|---|---|---|
| `Top Shell.stl` | 1 | Display window, encoder hole, 8-key grid |
| `Bottom Shell.stl` | 1 | Base |
| `Key Cap Terminal / Yes / Mic / No.stl` | 1 each | Utility keys — print **white** |
| `Key Cap Fox / Owl / Cat / Panda.stl` | 1 each | Agent keys — print in 4 **distinct colours** (red / blue / yellow / green) so you can tell agents apart at a glance without looking down |

**Multi-colour printing:** if you're swapping filament manually, print each
colour as a *separate job* rather than one multi-colour plate. A single plate
with colour changes forces the slicer to generate a purge/prime tower, which
wastes filament on 8 small parts. Separate jobs = no tower at all.

The `cad/dxf/` badge outlines are the icon geometry, if you want to remix the
keycaps. The four animal icons are traced from
[OpenMoji](https://openmoji.org/) (CC BY-SA 4.0); thin whiskers and talons were
morphologically removed because they don't survive FDM at keycap scale.

---

## Wiring

Full pin map in [`../docs/protocol-spec.md`](../docs/protocol-spec.md).

**Display + encoder module → XIAO**

| Module | XIAO |
|---|---|
| VCC | 3V3 (**not 5V**) |
| GND | GND |
| SDA | D4 |
| SCL | D5 |
| CLK | D3 |
| DT | D6 |
| SW | *unused* |

**8-key matrix** — rows `D0`, `D1`; columns `D7 D8 D9 D10` **left to right**.

| | C1 (D7) | C2 (D8) | C3 (D9) | C4 (D10) |
|---|---|---|---|---|
| **R1 (D0)** | TERM | MIC | FOX | PANDA |
| **R2 (D1)** | ENTER | X | CAT | OWL |

Each key: **row pin → switch leg A, switch leg B → column pin.** That's it.

⚠️ The column order was determined **empirically** — by pressing R1C1…R2C4 in
sequence and reading back what the device reported — and it is the reverse of
what the wiring notes suggested. If you rebuild this and keys come out
mirrored, that's why. Don't re-derive it from a diagram; measure it.

`D2` (GPIO3) is deliberately left unused: it's an ESP32-S3 **strapping pin**,
and a switch on it could interfere with boot-mode sensing if pressed at
power-on.

---

## Deliberately not in v0

| Item | Why |
|---|---|
| **LiPo battery (1200 mAh)** | Wired and tested, then cut. The bridge is USB-tethered anyway, so the battery only added a charging failure mode with no benefit. The XIAO's onboard charger handles it if you want it — mind the polarity |
| **External antenna** | The XIAO S3 ships with a u.FL FPC antenna and needs it for WiFi/BLE. v0 talks over USB serial, so it's unnecessary. If you add it later: stick it to an **inside plastic wall**, away from metal and the battery, and don't crease it |
| **Piezo buzzer** | Not bought, but **it's the single highest-value addition**. A silent flashing display can't get your attention when you aren't looking at it — which is the entire premise of the device. One chirp on "agent blocked" would be worth more than every visual affordance in this repo. v1 should populate one |

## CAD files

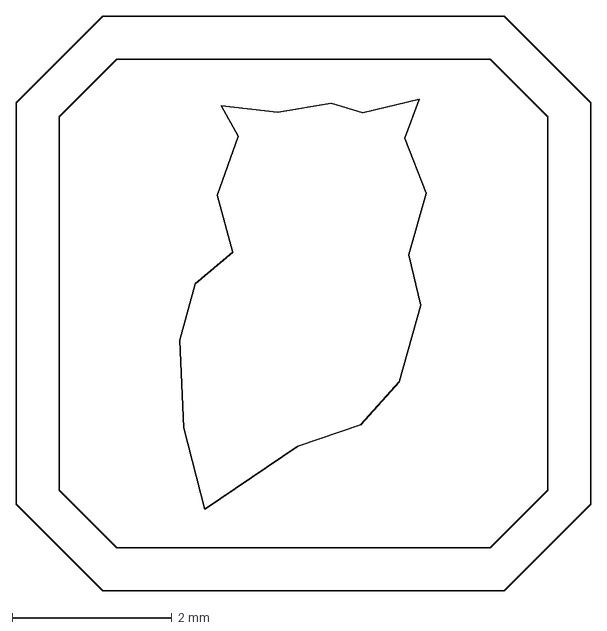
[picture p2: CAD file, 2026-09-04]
v0/cad/dxf/owl-badge.dxf
7.20 x 7.20 mm

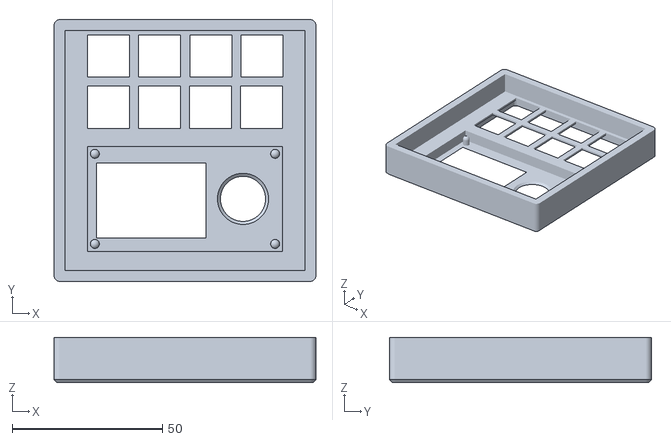
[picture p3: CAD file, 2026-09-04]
v0/cad/stl/Top Shell.stl
87.2 x 87.2 x 15.0

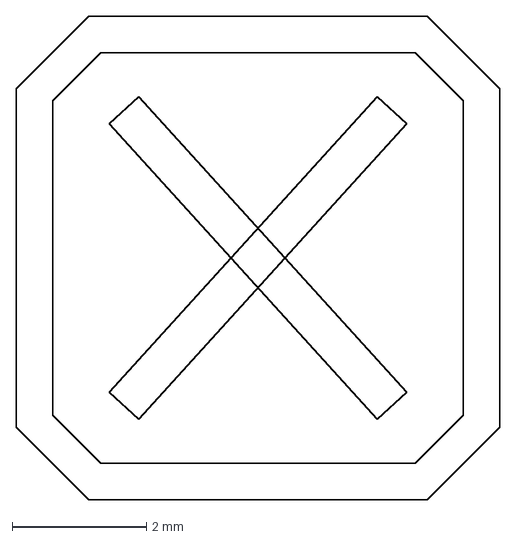
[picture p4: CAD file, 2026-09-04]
v0/cad/dxf/x-badge.dxf
7.20 x 7.20 mm

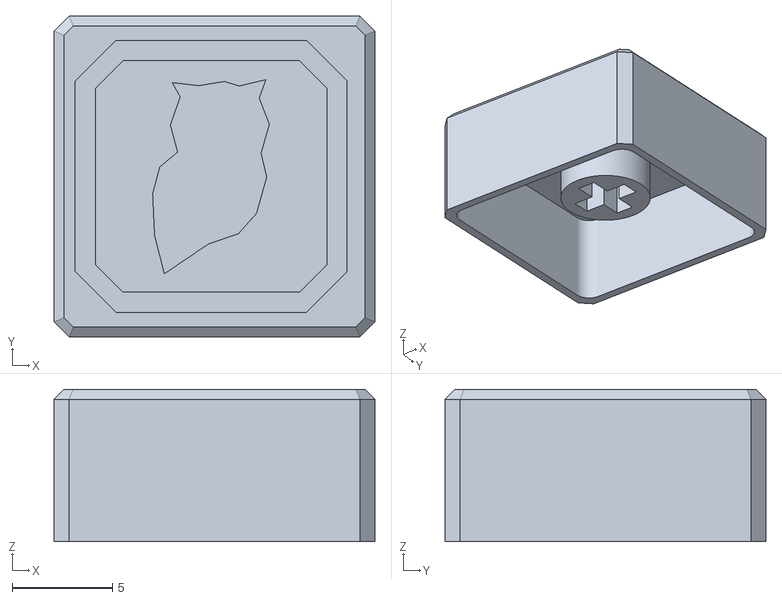
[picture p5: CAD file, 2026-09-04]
v0/cad/stl/Key Cap Owl.stl
16.0 x 16.0 x 7.60

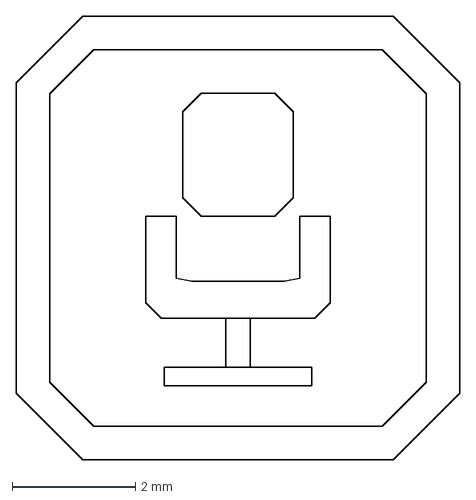
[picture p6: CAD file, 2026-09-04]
v0/cad/dxf/mic-badge.dxf
7.20 x 7.20 mm

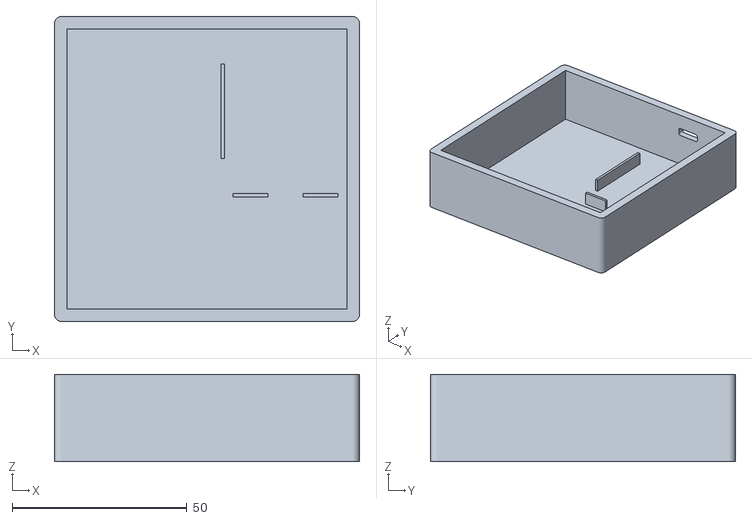
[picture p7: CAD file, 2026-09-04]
v0/cad/stl/Bottom Shell.stl
87.2 x 87.2 x 25.0

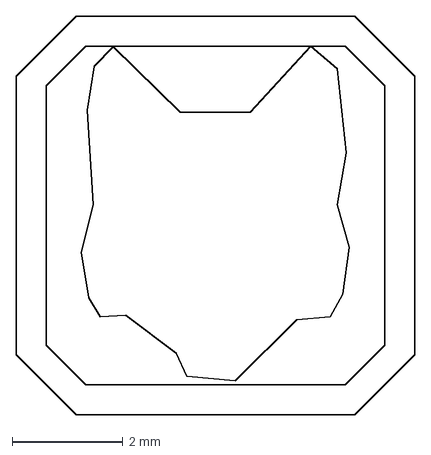
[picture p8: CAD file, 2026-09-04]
v0/cad/dxf/fox-badge.dxf
7.20 x 7.20 mm

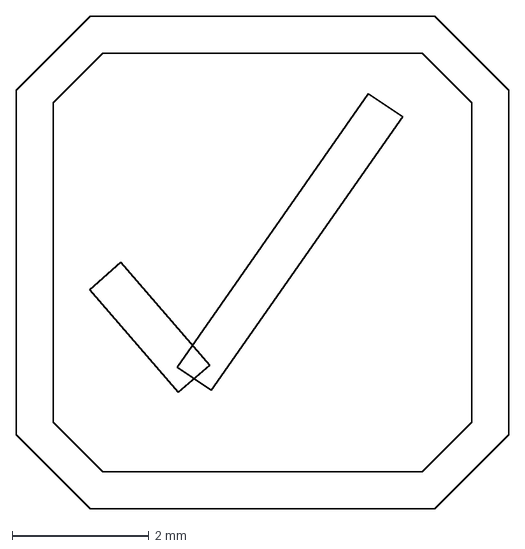
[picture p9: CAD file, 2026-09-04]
v0/cad/dxf/checkmark-badge.dxf
7.20 x 7.20 mm

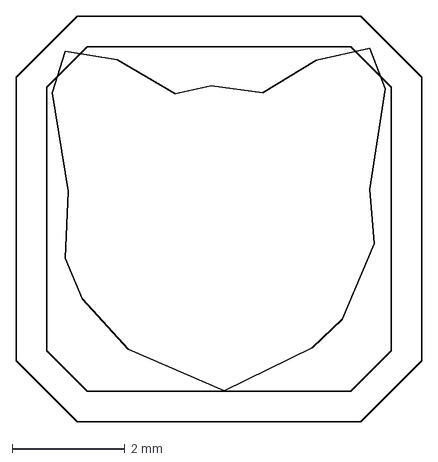
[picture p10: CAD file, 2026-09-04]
v0/cad/dxf/cat-badge.dxf
7.20 x 7.20 mm

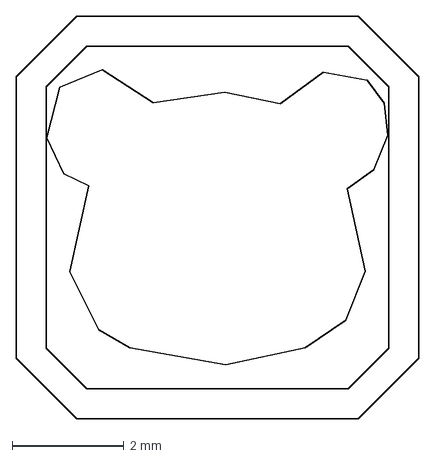
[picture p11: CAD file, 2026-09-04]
v0/cad/dxf/panda-badge.dxf
7.20 x 7.20 mm

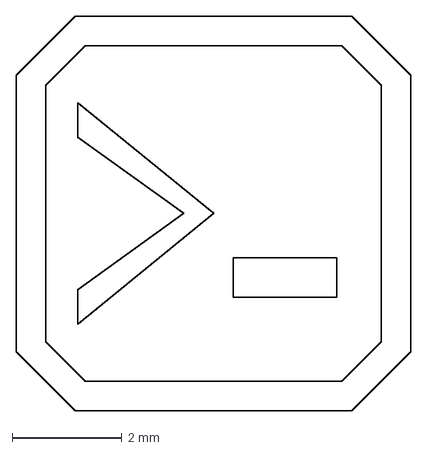
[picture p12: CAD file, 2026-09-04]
v0/cad/dxf/terminal-badge.dxf
7.20 x 7.20 mm

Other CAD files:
v0/cad/stl/Key Cap Mic.stl
v0/cad/stl/Key Cap Terminal.stl
v0/cad/stl/Key Cap Cat.stl
v0/cad/stl/Key Cap No.stl
v0/cad/stl/Key Cap Panda.stl
v0/cad/stl/Key Cap Yes.stl
v0/cad/stl/Key Cap Fox.stl

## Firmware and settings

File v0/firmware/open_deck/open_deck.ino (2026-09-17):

// Open Deck firmware.
//
// Hardware: XIAO ESP32S3 | SH1106 128x64 mono OLED (I2C) | EC11 encoder
// (rotation only; the push-switch on this module is dead) | 8 keys, 2x4 matrix.
//
// The deck emits semantic input events and renders whatever state the host
// pushes back. It knows nothing about tmux or any agent harness.
//
// Device -> host:
//   EVT <KEY_NAME> DOWN|HOLD|UP
//   EVT ENCODER <+1|-1>
//   HB <uptime_ms>
// Host -> device:
//   FACE <alert|busy|done|calm>
//   TOAST <text>
//   LIST <title>|<row>|...
//   PEEK <cursor>|<bar>|<row>|...   (empty payload clears it)
//        cursor is the row to draw inverted, or -1 for none

#include <Wire.h>
#include <Adafruit_GFX.h>
#include <Adafruit_SH110X.h>
#include "pixie_eyes.h"

#define OLED_ADDR    0x3C
#define SDA_PIN      D4
#define SCL_PIN      D5
#define ENC_CLK_PIN  D3
#define ENC_DATA_PIN D6

// Physical layout (index = row * 4 + col):
//   R1C1 TERM   R1C2 MIC     R1C3 FOX(1)  R1C4 PANDA(4)
//   R2C1 ENTER  R2C2 CANCEL  R2C3 CAT(3)  R2C4 OWL(2)
// Column order was verified by pressing R1C1..R2C4 in sequence and reading
// back what the device reported; it is the reverse of the wiring diagram.
const uint8_t ROW_PINS[2] = { D0, D1 };
const uint8_t COL_PINS[4] = { D7, D8, D9, D10 };

const char* KEY_NAMES[8] = {
  "KEY_TERM",  "KEY_MIC",    "KEY_AGENT1", "KEY_AGENT4",
  "KEY_ENTER", "KEY_CANCEL", "KEY_AGENT3", "KEY_AGENT2"
};



Adafruit_SH1106G display(128, 64, &Wire, -1);
RoboEyes<Adafruit_SH1106G> eyes(display);

// ---------- input ----------
bool keyState[8]    = {false};
bool keyRaw[8]      = {false};
bool keyHoldSent[8] = {false};
unsigned long keyChangeTime[8] = {0};
unsigned long keyDownTime[8]   = {0};
const unsigned long DEBOUNCE_MS = 25;
const unsigned long HOLD_MS     = 400;

static const int8_t ROT_TABLE[] = {0,1,1,0,1,0,0,1,1,0,0,1,0,1,1,0};
static uint8_t rotCode = 0;
static uint16_t rotStore = 0;

// ---------- face ----------
enum PixieState { PX_CALM, PX_BUSY, PX_ALERT, PX_DONE, PX_OFFLINE };
PixieState pixieState = PX_CALM;

char toastText[22] = "";
unsigned long toastUntil = 0;
bool toastDrawn = false;
const unsigned long TOAST_MS = 1800;

#define LIST_ROWS 6
char listRows[LIST_ROWS][22];

int  listCount = 0;
unsigned long listUntil = 0;
bool listDrawn = false;
const unsigned long LIST_MS = 1200;

// plumber: rendering runs on the second core. A full SH1106 framebuffer flush
// blocks for ~29.5ms (measured), and RoboEyes wants a frame every 20ms - so on
// a single thread the display is saturated and readRotary() is never called
// during the flush. Encoder detents last only a few ms, so they were not
// arriving late, they were being dropped. Input now owns core 1 exclusively.
// Attention pulse: invertDisplay() is a single command byte, not a framebuffer
// write, so flashing costs nothing next to a ~29.5ms flush. A burst on entry
// catches the eye; a short repeat every 10s keeps a standing alert visible
// without being maddening.
int flashTicks = 0;
unsigned long flashNext = 0;
unsigned long lastPulse = 0;
const unsigned long FLASH_MS = 110;
const unsigned long PULSE_INTERVAL_MS = 10000;

portMUX_TYPE faceMux = portMUX_INITIALIZER_UNLOCKED;
volatile int sharedState = PX_CALM;
volatile bool toastDirty = false;
char sharedToast[22] = "";

volatile bool listDirty = false;
char sharedList[LIST_ROWS][22];
int  sharedListCount = 0;

volatile unsigned long lastHostCommand = 0;

// The slot strip: four projects, four states, readable across a desk. This is
// the one thing on screen that says *which* agent wants you - the face only
// says whether any of them does.
// Peek: what a held key will do. Unlike a toast it has no timeout - it is on
// screen exactly as long as the finger is down, so it cannot be missed and
// cannot linger.
char sharedPeek[6][22];
volatile int  sharedPeekCount = 0;
volatile bool peekDirty = false;
volatile int  sharedPeekCursor = -1;
int  peekCursor = -1;
char peekRows[6][22];
int  peekCount = 0;
bool peekDrawn = false;
bool peekWasShown = false;


const unsigned long OFFLINE_AFTER_MS = 5000;
const unsigned long BLANK_AFTER_MS   = 15UL * 60 * 1000;
bool offlineToastShown = false;
bool panelBlanked = false;

// Drawn into the same framebuffer as the face, immediately before the single
// flush, so it never blinks.
// An inverted bar is the strongest, cheapest hierarchy device a one-bit panel
// has: it separates "what this is" from "what it says" without a second font.
void drawTitleBar(const char *text) {
  display.fillRect(0, 0, 128, 13, SH110X_WHITE);
  display.setTextSize(1);
  display.setTextColor(SH110X_BLACK);
  display.setCursor(3, 3);
  display.print(text);
  display.setTextColor(SH110X_WHITE);
}

void drawPeek() {
  display.clearDisplay();
  drawTitleBar(peekRows[0]);

  int rows = peekCount - 1;
  if (rows < 1) { display.display(); peekDrawn = true; return; }

  // One size for every row count. Double-height type looked shouty for what
  // this is - a list you scan, not a headline - and it cropped names that
  // fit fine at normal size.
  bool big = false;
  int line  = 12;
  int top   = 13 + (51 - rows * line) / 2;   // centre the block under the bar

  display.setTextSize(big ? 2 : 1);
  for (int i = 1; i <= rows; i++) {
    int y = top + (i - 1) * line;

    // The selected row is inverted rather than marked with a character: on a
    // one-bit panel that reads instantly and costs no width.
    bool selected = (i == peekCursor);
    if (selected) {
      display.fillRect(0, y - 2, 128, line, SH110X_WHITE);
      display.setTextColor(SH110X_BLACK);
    } else {
      display.setTextColor(SH110X_WHITE);
    }
    display.setCursor(2, y);
    // Size 2 fits 10 characters; cropping here rather than on the host keeps
    // the host from having to know which size the device picked.
    if (big) {
      char cropped[11];
      strncpy(cropped, peekRows[i], 10);
      cropped[10] = '\0';
      display.print(cropped);
    } else {
      display.print(peekRows[i]);
    }
  }
  display.setTextColor(SH110X_WHITE);

  display.display();
  peekDrawn = true;
}

void emit(const String &line) {
  // ESP32-S3 native USB CDC blocks once its TX ring fills with no host
  // reading, which would stall the key scan and the face along with it.
  if (Serial.availableForWrite() >= (int)line.length() + 2) Serial.println(line);
}

int8_t readRotary() {
  rotCode <<= 2;
  if (digitalRead(ENC_DATA_PIN)) rotCode |= 0x02;
  if (digitalRead(ENC_CLK_PIN))  rotCode |= 0x01;
  rotCode &= 0x0f;
  if (ROT_TABLE[rotCode]) {
    rotStore = (rotStore << 4) | rotCode;
    if ((rotStore & 0xff) == 0x2b) return -1;
    if ((rotStore & 0xff) == 0x17) return 1;
  }
  return 0;
}

// Runs on the render core only.
void applyState(PixieState next) {
  if (next == pixieState) return;
  pixieState = next;

  // Moving straight between two moods' eyelid shapes leaves erase artifacts,
  // so settle through DEFAULT and let each transition be a smaller delta.
  eyes.open();
  eyes.setMood(DEFAULT);
  eyes.setCuriosity(false);
  eyes.setIdleMode(ON, 3, 2);
  eyes.setAutoblinker(ON, 3, 2);

  switch (next) {
    case PX_BUSY:
      eyes.setMood(DEFAULT);
      eyes.setCuriosity(true);
      break;
    case PX_ALERT:
      eyes.setMood(ANGRY);
      eyes.setIdleMode(OFF);
      eyes.setPosition(DEFAULT);
      flashTicks = 6;
      flashNext = 0;
      lastPulse = millis();
      break;
    case PX_DONE:
      eyes.setMood(HAPPY);
      eyes.anim_laugh();
      break;
    case PX_OFFLINE:
      eyes.setMood(DEFAULT);
      eyes.setIdleMode(OFF);
      eyes.setAutoblinker(OFF);
      eyes.close();
      break;
    default:
      eyes.setMood(DEFAULT);
      break;
  }
}

PixieState parseState(const String &name) {
  if (name == "busy")  return PX_BUSY;
  if (name == "alert") return PX_ALERT;
  if (name == "done")  return PX_DONE;
  return PX_CALM;
}

void showToast(const String &text) {
  portENTER_CRITICAL(&faceMux);
  strncpy(sharedToast, text.c_str(), sizeof(sharedToast) - 1);
  sharedToast[sizeof(sharedToast) - 1] = '\0';
  toastDirty = true;
  portEXIT_CRITICAL(&faceMux);
}

void showList(const String &payload) {
  portENTER_CRITICAL(&faceMux);
  sharedListCount = 0;
  int start = 0;
  while (sharedListCount < LIST_ROWS && start <= (int)payload.length()) {
    int bar = payload.indexOf('|', start);
    String field = (bar < 0) ? payload.substring(start) : payload.substring(start, bar);
    strncpy(sharedList[sharedListCount], field.c_str(), 21);
    sharedList[sharedListCount][21] = '\0';
    sharedListCount++;
    if (bar < 0) break;
    start = bar + 1;
  }
  listDirty = true;
  portEXIT_CRITICAL(&faceMux);
}

// Toast text is static, so it is drawn and flushed once rather than every
// frame - the face resumes when it expires.
void drawToast() {
  display.clearDisplay();
  display.setTextSize(1);
  display.setTextColor(SH110X_WHITE);
  bool big = strlen(toastText) <= 10;
  display.setTextSize(big ? 2 : 1);
  int width = strlen(toastText) * (big ? 12 : 6);
  int x = (128 - width) / 2;
  display.setCursor(x < 0 ? 0 : x, big ? 24 : 28);
  display.print(toastText);
  display.display();
  toastDrawn = true;
}

void drawList() {
  display.clearDisplay();
  drawTitleBar(listRows[0]);
  display.setTextSize(1);
  for (int i = 1; i < listCount; i++) {
    display.setCursor(4, 6 + i * 11);
    display.print(listRows[i]);
  }
  display.display();
  listDrawn = true;
}

String nextToken(const String &s, int &pos) {
  while (pos < (int)s.length() && s[pos] == ' ') pos++;
  int start = pos;
  while (pos < (int)s.length() && s[pos] != ' ') pos++;
  return s.substring(start, pos);
}

void handleCommand(const String &line) {
  lastHostCommand = millis();

  int pos = 0;
  String cmd = nextToken(line, pos);

  if (cmd == "FACE") {
    sharedState = parseState(nextToken(line, pos));
  } else if (cmd == "TOAST") {
    while (pos < (int)line.length() && line[pos] == ' ') pos++;
    showToast(line.substring(pos));
  } else if (cmd == "PEEK") {
    while (pos < (int)line.length() && line[pos] == ' ') pos++;
    String body = line.substring(pos);
    // First field is the cursor row, then the bar, then the pane rows.
    int firstBar = body.indexOf('|');
    int cur = -1;
    if (firstBar > 0) {
      cur = body.substring(0, firstBar).toInt();
      body = body.substring(firstBar + 1);
    }
    portENTER_CRITICAL(&faceMux);
    sharedPeekCursor = cur;
    sharedPeekCount = 0;
    int start = 0;
    while (body.length() && sharedPeekCount < 6) {
      int bar = body.indexOf('|', start);
      String row = bar < 0 ? body.substring(start) : body.substring(start, bar);
      row.toCharArray(sharedPeek[sharedPeekCount], 22);
      sharedPeekCount++;
      if (bar < 0) break;
      start = bar + 1;
    }
    peekDirty = true;
    portEXIT_CRITICAL(&faceMux);
  } else if (cmd == "LIST") {
    while (pos < (int)line.length() && line[pos] == ' ') pos++;
    showList(line.substring(pos));
  }
}

void pollHost() {
  static String buf;
  while (Serial.available()) {
    char c = (char)Serial.read();
    if (c == '\n') {
      buf.trim();
      if (buf.length()) handleCommand(buf);
      buf = "";
    } else if (c != '\r' && buf.length() < 200) {
      buf += c;
    }
  }
}

void scanMatrix() {
  for (uint8_t r = 0; r < 2; r++) {
    // Rows are OUTPUT_OPEN_DRAIN: LOW sinks, HIGH releases rather than
    // sources, so two keys sharing a column across rows cannot short one
    // row's output into the other.
    digitalWrite(ROW_PINS[r], LOW);
    delayMicroseconds(20);

    for (uint8_t c = 0; c < 4; c++) {
      uint8_t idx = r * 4 + c;
      bool raw = !digitalRead(COL_PINS[c]);

      if (raw != keyRaw[idx]) {
        keyRaw[idx] = raw;
        keyChangeTime[idx] = millis();
      }
      if (millis() - keyChangeTime[idx] > DEBOUNCE_MS && keyState[idx] != keyRaw[idx]) {
        keyState[idx] = keyRaw[idx];
        if (keyState[idx]) {
          keyDownTime[idx] = millis();
          keyHoldSent[idx] = false;
          emit(String("EVT ") + KEY_NAMES[idx] + " DOWN");
        } else {
          emit(String("EVT ") + KEY_NAMES[idx] + " UP");
        }
      }
      if (keyState[idx] && !keyHoldSent[idx] && millis() - keyDownTime[idx] >= HOLD_MS) {
        keyHoldSent[idx] = true;
        emit(String("EVT ") + KEY_NAMES[idx] + " HOLD");
      }
    }
    digitalWrite(ROW_PINS[r], HIGH);
  }
}

void setup() {
  Serial.begin(115200);
  delay(300);
  randomSeed(micros());

  Wire.begin(SDA_PIN, SCL_PIN);
  Wire.setClock(400000);

  pinMode(ENC_CLK_PIN, INPUT_PULLUP);
  pinMode(ENC_DATA_PIN, INPUT_PULLUP);
  for (uint8_t r = 0; r < 2; r++) {
    pinMode(ROW_PINS[r], OUTPUT_OPEN_DRAIN);
    digitalWrite(ROW_PINS[r], HIGH);
  }
  for (uint8_t c = 0; c < 4; c++) pinMode(COL_PINS[c], INPUT_PULLUP);


  if (!display.begin(OLED_ADDR, true)) {
    Serial.println("SH1106 init failed");
    while (1) delay(1000);
  }

  eyes.begin(128, 64, 50);
  eyes.setWidth(34, 34);
  eyes.setHeight(34, 34);
  eyes.setBorderradius(10, 10);
  eyes.setSpacebetween(12);
  eyes.setAutoblinker(ON, 3, 2);
  eyes.setIdleMode(ON, 3, 2);

  // Confirms the panel and I2C bus are alive before any host is involved.
  eyes.close();
  for (int i = 0; i < 12; i++) { eyes.update(); delay(25); }
  eyes.open();
  for (int i = 0; i < 12; i++) { eyes.update(); delay(25); }
  eyes.blink();
  for (int i = 0; i < 20; i++) { eyes.update(); delay(25); }

  // The 5s offline window exists to tolerate a host going quiet, and boot is
  // exactly when a quiet host is expected - the daemon starts seconds after
  // the deck powers up. Seeded before the render task starts, so core 0 can
  // never observe the unset value and flash the offline face.
  lastHostCommand = millis();

  // Arduino's loopTask runs on core 1, so rendering goes to core 0.
  xTaskCreatePinnedToCore(renderTask, "render", 4096, nullptr, 1, nullptr, 0);

  Serial.println("Open Deck ready");
}

void renderTask(void *) {
  for (;;) {
    portENTER_CRITICAL(&faceMux);
    bool newToast = toastDirty;
    if (newToast) {
      strncpy(toastText, sharedToast, sizeof(toastText));
      toastDirty = false;
    }
    portEXIT_CRITICAL(&faceMux);

    if (newToast) {
      toastUntil = millis() + TOAST_MS;
      toastDrawn = false;
    }

    portENTER_CRITICAL(&faceMux);
    bool newList = listDirty;
    if (newList) {
      for (int i = 0; i < sharedListCount; i++) strncpy(listRows[i], sharedList[i], 22);
      listCount = sharedListCount;
      listDirty = false;
    }
    portEXIT_CRITICAL(&faceMux);
    if (newList) {
      listUntil = millis() + LIST_MS;
      listDrawn = false;
    }

    portENTER_CRITICAL(&faceMux);
    bool newPeek = peekDirty;
    if (newPeek) {
      for (int i = 0; i < sharedPeekCount; i++) strncpy(peekRows[i], sharedPeek[i], 22);
      peekCount = sharedPeekCount;
      peekCursor = sharedPeekCursor;
      peekDirty = false;
    }
    portEXIT_CRITICAL(&faceMux);
    if (newPeek) peekDrawn = false;

    // Held key: show it and nothing else, for as long as it is held.
    if (peekCount > 0) {
      if (!peekDrawn) { drawPeek(); peekWasShown = true; }
      vTaskDelay(pdMS_TO_TICKS(20));
      continue;
    }

    bool hostAlive = lastHostCommand && (millis() - lastHostCommand < OFFLINE_AFTER_MS);
    if (!hostAlive) {
      if (!offlineToastShown) {
        offlineToastShown = true;
        showToast("host offline");
      }
      applyState(PX_OFFLINE);
    } else {
      offlineToastShown = false;
      if (panelBlanked) {
        panelBlanked = false;
        display.clearDisplay();
      }
      applyState(static_cast<PixieState>(sharedState));
    }

    // Nothing live is being shown, so there is nothing to lose by blanking -
    // and a static face would retain on a mono OLED.
    if (!hostAlive && lastHostCommand &&
        millis() - lastHostCommand > BLANK_AFTER_MS) {
      if (!panelBlanked) {
        panelBlanked = true;
        display.clearDisplay();
        display.display();
      }
      vTaskDelay(pdMS_TO_TICKS(200));
      continue;
    }

    if (flashTicks > 0) {
      if (millis() >= flashNext) {
        display.invertDisplay(flashTicks % 2 == 0);
        flashNext = millis() + FLASH_MS;
        if (--flashTicks == 0) display.invertDisplay(false);
      }
    } else if (pixieState == PX_ALERT &&
               millis() - lastPulse >= PULSE_INTERVAL_MS) {
      lastPulse = millis();
      flashTicks = 2;
      flashNext = 0;
    }

    if (millis() < toastUntil) {
      if (!toastDrawn) drawToast();
      vTaskDelay(pdMS_TO_TICKS(20));
    } else if (millis() < listUntil) {
      if (!listDrawn) drawList();
      vTaskDelay(pdMS_TO_TICKS(20));
    } else {
      // update() now reports whether it drew, so the strip goes into the same
      // frame and the whole thing costs one flush instead of two.
      if (peekWasShown) {      // peek just cleared; repaint from scratch
        peekWasShown = false;
        display.clearDisplay();
        eyes.open();
      }
      // Home is the face and nothing else.
      if (eyes.update()) display.display();
      vTaskDelay(1);
    }
  }
}

unsigned long lastHeartbeat = 0;

void loop() {
  int8_t dir = readRotary();
  if (dir != 0) {
    emit(String("EVT ENCODER ") + (dir > 0 ? "+1" : "-1"));
  }

  scanMatrix();
  pollHost();

  if (millis() - lastHeartbeat >= 1000) {
    lastHeartbeat = millis();
    emit(String("HB ") + millis());
  }

  delayMicroseconds(200);
}

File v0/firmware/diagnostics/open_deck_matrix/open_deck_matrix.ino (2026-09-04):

// Open Deck - full 8-key matrix + encoder + OLED status firmware
//
// Only row0/col0 (the "Terminal" key) is physically wired right now —
// the rest of the matrix will just read "up" until the other 7 keys
// and the rest of the case are wired in. Scan logic is written for the
// full matrix so nothing needs to change firmware-side once they're
// connected; just start printing more DOWN events for those keys.
//
// Key layout: physical 2 rows x 4 cols (matches the case layout).
//   row D0: R1C1 Terminal  R1C2 Enter(check)  R1C3 Fox   R1C4 Owl
//   row D1: R2C1 Voice(mic) R2C2 Cancel(X)    R2C3 Cat   R2C4 Panda
// Cols in pin order: C1=D10 C2=D9 C3=D8 C4=D7
// (D2 = GPIO3, an ESP32-S3 strapping pin - avoided here since a switch
// sitting on it could interfere with boot-mode sensing if pressed right
// at power-on. D7 = GPIO44, plain GPIO, no such risk.)
//
// Only R1C1 has a diode (first key wired, before we decided the rest of
// the matrix doesn't need them - no simultaneous-chord functionality
// planned, so ghosting risk is negligible for a macro pad). All other
// 7 keys are wired switch-only, straight from row pin to col pin.
//
// Encoder push-switch dropped from scope (dead on this module, confirmed
// via raw_io_test.ino) - D7 is free for future use.

#include <Wire.h>
#include <Adafruit_GFX.h>
#include <Adafruit_SH110X.h>

// --- Display ---
#define OLED_ADDR   0x3C
#define SDA_PIN     D4
#define SCL_PIN     D5
Adafruit_SH1106G display(128, 64, &Wire, -1);

// --- Encoder ---
#define ENC_DATA_PIN D6  // DT
#define ENC_CLK_PIN  D3  // CLK

// --- Key matrix: 2 rows x 4 cols = 8 keys ---
const uint8_t ROW_PINS[2] = { D0, D1 };
const uint8_t COL_PINS[4] = { D10, D9, D8, D7 };

// row-major: idx = row*4 + col
const char* KEY_NAMES[8] = {
  "TERM", "ENTR", "FOX", "OWL",   // row D0 (R1C1..R1C4)
  "MIC",  "X",    "CAT", "PNDA"  // row D1 (R2C1..R2C4) - "PNDA" so it fits the 30px box (4 chars max at 6px/char)
};

bool keyState[8]       = { false, false, false, false, false, false, false, false };
bool keyStateRaw[8]    = { false, false, false, false, false, false, false, false };
unsigned long keyChangeTime[8] = { 0 };
const unsigned long DEBOUNCE_MS = 25;

// --- Encoder read (polled, debounced lookup-table method) ---
static const int8_t rot_enc_table[] = {0,1,1,0,1,0,0,1,1,0,0,1,0,1,1,0};
static uint8_t prevNextCode = 0;
static uint16_t store = 0;

int8_t read_rotary() {
  prevNextCode <<= 2;
  if (digitalRead(ENC_DATA_PIN)) prevNextCode |= 0x02;
  if (digitalRead(ENC_CLK_PIN))  prevNextCode |= 0x01;
  prevNextCode &= 0x0f;

  if (rot_enc_table[prevNextCode]) {
    store <<= 4;
    store |= prevNextCode;
    if ((store & 0xff) == 0x2b) return -1;
    if ((store & 0xff) == 0x17) return 1;
  }
  return 0;
}

// ESP32-S3's native USB CDC Serial blocks on write once its internal TX
// ring buffer fills, if nothing on the host side is actively draining it
// (unlike a classic USB-UART bridge chip, which just drops bytes). Since
// these prints happen inline in loop(), a blocked write would stall the
// matrix scan AND the display push right along with it - so never print
// unless there's room, drop the line instead of blocking.
void serialPrintlnSafe(const String &line) {
  if (Serial.availableForWrite() >= (int)line.length() + 2) {
    Serial.println(line);
  }
}

long encoderCount = 0;

bool displayDirty = true; // start true so the initial grid gets drawn

void scanMatrix() {
  for (uint8_t r = 0; r < 2; r++) {
    // rows are OUTPUT_OPEN_DRAIN (set once in setup()): driving LOW still
    // actively sinks the active row, but driving HIGH just releases the
    // pin to float instead of sourcing current - same short-circuit
    // protection as a true Hi-Z idle row (two keys sharing a column
    // across different rows can't short one row's drive into another's),
    // but with plain fast digitalWrite() instead of pinMode() every scan.
    digitalWrite(ROW_PINS[r], LOW);
    delayMicroseconds(20); // let the line settle before reading

    for (uint8_t c = 0; c < 4; c++) {
      uint8_t idx = r * 4 + c;
      bool raw = !digitalRead(COL_PINS[c]); // LOW = pressed (row driven low, switch pulls col low)

      if (raw != keyStateRaw[idx]) {
        keyStateRaw[idx] = raw;
        keyChangeTime[idx] = millis();
      }
      if (millis() - keyChangeTime[idx] > DEBOUNCE_MS && keyState[idx] != keyStateRaw[idx]) {
        keyState[idx] = keyStateRaw[idx];
        serialPrintlnSafe(String("KEY ") + KEY_NAMES[idx] + " " + (keyState[idx] ? "DOWN" : "up"));
        displayDirty = true;
      }
    }

    digitalWrite(ROW_PINS[r], HIGH); // release (open-drain HIGH = floating, not driven)
  }
}

void drawStatus() {
  display.clearDisplay();
  display.setTextColor(SH110X_WHITE);

  display.setTextSize(1);
  display.setCursor(0, 0);
  display.print("OPEN DECK  enc:");
  display.println(encoderCount);
  display.drawLine(0, 10, 127, 10, SH110X_WHITE);

  // 2x4 grid of key boxes mirroring the physical layout
  const int boxW = 30, boxH = 24, gapX = 2, gapY = 2, originX = 2, originY = 14;
  for (uint8_t r = 0; r < 2; r++) {
    for (uint8_t c = 0; c < 4; c++) {
      uint8_t idx = r * 4 + c;
      int x = originX + c * (boxW + gapX);
      int y = originY + r * (boxH + gapY);
      if (keyState[idx]) {
        display.fillRect(x, y, boxW, boxH, SH110X_WHITE);
        display.setTextColor(SH110X_BLACK);
      } else {
        display.drawRect(x, y, boxW, boxH, SH110X_WHITE);
        display.setTextColor(SH110X_WHITE);
      }
      display.setCursor(x + 3, y + 7);
      display.print(KEY_NAMES[idx]);
    }
  }
  display.display();
}

void setup() {
  Serial.begin(115200);
  delay(1500);

  Wire.begin(SDA_PIN, SCL_PIN);
  Wire.setClock(400000);

  pinMode(ENC_DATA_PIN, INPUT_PULLUP);
  pinMode(ENC_CLK_PIN, INPUT_PULLUP);

  for (uint8_t r = 0; r < 2; r++) {
    pinMode(ROW_PINS[r], OUTPUT_OPEN_DRAIN);
    digitalWrite(ROW_PINS[r], HIGH); // idle = released/floating, not driven (see scanMatrix())
  }
  for (uint8_t c = 0; c < 4; c++) {
    pinMode(COL_PINS[c], INPUT_PULLUP);
  }

  if (!display.begin(OLED_ADDR, true)) {
    Serial.println("SH1106 init failed - check wiring/address");
    while (1) delay(1000);
  }

  Serial.println("Open Deck matrix firmware ready");
  drawStatus();
}

unsigned long lastDraw = 0;
const unsigned long MIN_DRAW_INTERVAL_MS = 15; // coalesce fast encoder spins into fewer I2C pushes
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

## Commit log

2026-09-04 Open Deck: physical control surface for terminal AI agents
    Firmware (XIAO ESP32S3), host bridge daemon, Claude Code hooks and
    per-harness profiles. Answers "which agent needs me, and what does it
    want?" on a dedicated display so you don't have to switch windows.
    Verified on hardware end to end:
    physical key -> firmware gate -> serial -> bridge -> tmux -> agent pane
    Notable: the approve gate is enforced in firmware by withholding the
    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
    [Bottom Shell.stl, Key Cap Cat.stl, Key Cap Fox.stl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]
2026-09-04 Reorganize into v0/ and add BOM
    v0 is the hand-wired breadboard build: firmware, bridge daemon, CAD, and
    diagnostics all live under v0/. v1 (custom PCB) will sit alongside it.
    Adds a full BOM with the parts actually used, the empirically-verified
    pin map, and the caveats that cost real debugging time - the display is
    SH1106 not SSD1306, the column order is the reverse of the wiring notes,
    and our encoder's push-switch was dead on arrival.
    [Bottom Shell.stl, Key Cap Cat.stl, Key Cap Fox.stl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]
2026-09-10 Rebuild around tmux; add Pixie; fix dropped encoder events
    Four animal keys now map to four tmux sessions and the encoder steps
    through panes within one. tmux already tracks per-window activity and
    bell flags, so the "something happened where you aren't looking" signal
    comes free for any harness - no hooks, no settings.json, no scraping.
    Drops the Claude-Code-specific hook server and the approval flow, which
    were mutually exclusive with --dangerously-skip-permissions anyway.
    Host daemon rewritten into single-purpose modules (transport, gestures,
    tmux, terminal, slots, presence, face, actions, controller, config) with
    declarative bindings resolved from a registry. 95 tests, no hardware or
    tm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
2026-09-10 Flash the screen on attention, name the session, run at login
    Attention alerts now invert the display three times on entry and
    re-pulse every 10s while they stand. invertDisplay() is a single command
    byte rather than a framebuffer write, so this costs nothing next to the
    ~29.5ms a redraw takes - no extra hardware needed.
    The toast names which session wants you ("OWL wants you"); "something
    wants you" is not actionable on its own.
    scripts/install-service.sh installs a launchd agent so the daemon
    survives closing the terminal. It pins PATH explicitly - launchd starts
    with a minimal one, and without it tmux and the terminal app are
    unreachable and every action silently no-ops.
    Verified again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
    [open_deck.ino]
2026-09-10 Design: wire Pixie in as the display layer
    Splits the display by time rather than by screen area - Pixie rests,
    the pane list appears while you interact, alerts interrupt. Collapses
    six face states to four (idle and active rendered identically, and
    asleep was presentation rather than meaning), adds an honest offline
    state so the display cannot lie about being live, and folds the summon
    toast into the pane list.
2026-09-10 test: pin newline-stripping behavior in pane list payload
2026-09-10 feat: reveal the pane list on encoder turn and summon
2026-09-10 fix: summon shows its own session's panes, not the attached one
2026-09-10 fix: seed lastHostCommand at boot to avoid instant offline flash
    [open_deck.ino]
2026-09-10 fix: seed lastHostCommand before render task starts, not after
    [open_deck.ino]
2026-09-11 fix: thread window into pane_label so deliberate window names render
    build_list called pane_label(pane, None) unconditionally, so preference
    rule 1 (a deliberate window name beats the running command) never fired
    in the shipped product - only pane_label's direct unit tests exercised
    that path. build_list now maps windows by index once and passes the
    matching Window into pane_label, reusing the same lookup for the
    activity/bell flag instead of scanning the window list twice per row.
    Also drop panes.py's private copy of the generic-shell-name set and
    import tmux._GENERIC_WINDOW_NAMES instead, removing a third duplicate.
    Added regression tests in TestBuildList (not TestPaneLabel) covering
    bot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
2026-09-11 Design: HID keyboard as a second, install-free tier
    The deck is inert without its daemon today, so using it on another
    machine means cloning a repo and building a venv. ESP32-S3 can enumerate
    as composite HID+CDC, giving three tiers: bare keystrokes with nothing
    installed, session switching with six lines of .tmux.conf, and the full
    tmux/Pixie experience where the daemon runs.
    Verified before designing: the board currently builds as USBMode=hwcdc,
    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
2026-09-11 feat: send HID keystrokes when no daemon is listening
    The deck now enumerates as a composite HID+CDC device, so a machine with
    nothing installed still gets working keys: Enter, Escape, Space, and
    F13-F19 for the project keys and encoder. F13-F24 are keycodes almost
    nothing binds, so they are safe to send blind - inert on a bare machine,
    bindable in .tmux.conf where more is wanted.
    Arbitration reuses the existing offline watchdog rather than adding
    state, with asymmetric thresholds: 5s when no host has ever spoken (a
    bare machine), 15s when one spoke and went quiet (probably a hiccup), so
    a stalled daemon cannot start typing Escape into a browser.
    Guarded on tud_hid_n_ready(). USBHIDKeyboar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
    [open_deck.ino]
2026-09-11 feat: real agent awareness and the approval flow
    tmux can only see that a process is running. Harness hooks can see which
    agent it is, whether it is thinking or stopped waiting on a decision,
    when it finished, and how full its context is. This adds that channel
    back and makes it outrank tmux inference wherever it exists, with tmux
    remaining the fallback for panes no hook has reported.
    The approval flow returns with it: an agent blocked on a permission
    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
2026-09-11 Remove the approval flow, keep the agent awareness
    The approve screen only ever fires when a harness actually asks for
    permission, and the launch command here is `cla` -
    claude --dangerously-skip-permissions - which never asks. Shipping a
    feature that is dormant by construction is worse than not shipping it:
    it carries a scroll gate, a destructive-command matcher, a modal screen
    and an input-suppression path, all of which must keep working and none
    of which ever run.
    What hooks give that tmux cannot is kept in full: which agent is in a
    pane, whether it is working or waiting on you, when it finished, and how
    full its context is. All of that fires regardless of the permission
    flag.
    150 tests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
    [open_deck.ino]
2026-09-11 Remove HID; the bare tier was not worth its hazard
    On a fresh machine HID delivered Enter, Escape, Space and six F-keys
    that do nothing until you edit .tmux.conf there - which needs tmux,
    sessions named after the animals, and a config edit. That is not zero
    install, it is a different install, and the machine already had a
    keyboard that types Enter.
    Against that it added a real misfire: a daemon stalled past 15s and the
    deck starts typing Escape into whatever window has focus. The asymmetric
    arming thresholds I built were engineering around a hazard that only
    existed because of a feature earning nothing.
    Also reverts to the default FQBN. TinyUSB was only needed for HID, and
    it cost a rename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
    [open_deck.ino]
2026-09-11 Design: standalone control surface via tmux command prompt
    tmux intercepts its prefix regardless of what occupies the pane, so
    `C-b : switch-client -t fox` works over the top of a running agent with
    no configuration at all. That is the difference from the earlier HID
    attempt, which sent F13-F19 and needed .tmux.conf bindings on every
    machine - making its bare tier three keystrokes you already had.
    Two safety guards become unnecessary rather than missing: TERM always
    splits first, so the pane it types into is always a fresh shell; and X
    sends only C-c, never `exit`, so it cannot destroy a pane without the
    state to know better.
    The display splits honestly. Rendering already lives on the devi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
2026-09-12 The deck is not a keyboard: delete HID, delete the host install
    HID was proposed to avoid a host install and removed twice. This settles it.
    The flaw is addressing, not keystroke length. `tmux send-keys -t fox:1.2`
    names a pane; HID names nothing and types into whatever holds focus. The
    product is "which agent needs me, act on that agent" — an addressing problem
    a keyboard cannot express. Today it typed `:select-pane -t :.+` into a live
    Claude Code session, and after each misfire was made smaller, `o;;ooo;;;ooo`.
    Smaller misfires was the wrong axis.
    Firmware: every keystroke path gone, back to the default hwcdc USB mode.
    That also drops the TinyUSB tax — the port no longer renames betw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
    [open_deck.ino]
2026-09-12 Spec: Pixie Deck, a product rather than a tmux accessory
    Diagnoses why v0 reads as a tool - keys bind to sessions that must already
    exist, binding is a hand-edited JSON file, and every feature is a tmux
    command in a costume - and reframes slots as projects the deck creates and
    owns. tmux becomes plumbing the owner never sees.
    Covers first run, a five-screen display system, a verb+target chord grammar
    that exploits the accidental left-verbs/right-targets layout, and what Pixie
    gets (reactions, a sense of time) versus what stays in Pixie's own repo
    (voice, wake word, brain).
2026-09-15 Slot strip, and a key that always means the same session
    Two product changes.
    Slots were filled by whatever sessions happened to exist, in discovery
    order, so a key's meaning depended on what you had started that morning. A
    physical button whose meaning moves is worse than no button. Slots are now
    fixed - FOX is fox, CAT is cat - and pressing a key creates the session if
    it is missing, so an unused key still does something. session_for() now
    always names a session, so the callers that used None to mean 'empty' ask
    exists() instead.
    The display gains a strip under Pixie: one mark per key, so the whole fleet
    reads at a glance. The face says whether anything wants you; the strip says
    which. T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
    [open_deck.ino, pixie_eyes.h]
2026-09-17 Verified on hardware: strip renders, empty key creates its session
    Flashed and confirmed: the slot strip draws under Pixie without flicker, the
    vendored RoboEyes patch holds (one flush per frame), and the face still
    animates correctly at the reduced height. Pressing CAT with no cat session
    created it, switched to it, and updated the strip.
2026-09-17 Peek: hold a key to see what it does
    A deck with gestures nobody can discover is a party trick. Holding any key
    now shows a panel naming it, its session's state, and what tap will do - so
    the device explains itself and there is no manual to lose.
    Hold previously interrupted that slot's session. Peeking has to be free or
    nobody explores, and a destructive action on the exploration gesture teaches
    exactly the wrong lesson, so hold is now non-destructive. Interrupt stays on
    X for the current session, and config.json can bind hold back for anyone who
    wants the old behaviour.
    PEEK has no timeout, unlike a toast: it goes up on the hold and comes down on
    release, tracking the finger. Releasing wi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
    [open_deck.ino]
2026-09-17 Redesign the display around a glance, not a text console
    The panel was being treated as a 21-column terminal: left-aligned rows, every
    line the same weight, and instructions that stop being useful after the first
    week. On a 128x64 one-bit panel read in under a second, that is the wrong
    shape entirely.
    Three changes, each removing something.
    The status strip becomes a 2x2 cluster beside Pixie, because the animal keys
    are a 2x2 block and a left-to-right strip mapped to nothing the hand knows.
    It drops its labels: the keycaps already say which key is which, so printing
    FOX OWL CAT PNDA spent half the pixels repeating the hardware. State is
    carried by fill - corners, outline, breathing, blinki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
    [open_deck.ino]
2026-09-17 Home is Pixie, and only Pixie
    The status cluster is gone and she has the whole 128x64 panel back. A resting
    screen should be a face, not a dashboard - which is the reason to keep the
    thing on a desk at all.
    Her expression still carries whether anything wants you; which one is a hold
    away. The SLOTS message had no consumer once the cluster went, so it is
    removed rather than left as a wire format nothing draws.
    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
2026-09-17 v0 PRD: context-aware keys, panes on hold, splitting as its own gesture
    Holding an animal now lists the session's panes - each with a mark for shell
    or agent, the active one flagged, and whatever the pane is best called. Rows
    scale to how many there are: one or two get double-size type, three or four
    drop to normal, so the panel is always full rather than always the same size.
    A plain terminal shows as zsh rather than being hidden, or the count on the
    deck would disagree with the count on screen.
    ENTER, X and MIC stop being fixed keystrokes. Each resolves against whatever
    is running in the pane: C-c interrupts a shell, Escape interrupts an agent
    without killing it, voice is Space in Claude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
    [open_deck.ino]
2026-09-17 The dial browses; ENTER goes there
    Turning the encoder used to switch panes on every detent, and the list was a
    readout of where you already were rather than a menu. Now the dial moves a
    cursor and nothing else moves - ENTER commits. Looking is free, which is the
    same rule that makes holding a key safe to explore.
    The selected row is drawn inverted rather than marked with a character: on a
    one-bit panel that reads instantly and costs no width.
    The real win is holding an animal: the dial then browses *that* session, so
    you can look inside a project you are not in and jump straight to one of its
    panes. Committing across sessions switches the client and focuses the
    terminal first.
    PEEK gains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
    [open_deck.ino]
2026-09-17 The dial previews where it can, and the list gives up on its own
    Three fixes from using it.
    Browsing showed nothing on the Mac, so you were choosing from names on a
    128x64 panel with no preview. The dial now follows along inside the session
    you are already in - your screen is the preview - while browsing another
    session still waits for ENTER, because a dial should not yank you out of what
    you are reading.
    The list stayed up until something was pressed. It is a look-and-go tool, not
    a mode: it now expires 2.5s after you stop touching the deck and the face
    comes back. A held key keeps its own panel up, so the countdown only starts
    once nothing is being pressed.
    Pane rows were double-height,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
    [open_deck.ino]
2026-09-17 Double-tap X closes the pane
    Tap X interrupts, double-tap closes - the same key twice for 'stop, then get
    rid of it'. Closing runs exit rather than kill-pane: it is what a shell
    expects, it lets the shell clean up, and closing the last pane ending the
    session is tmux's own behaviour rather than something the deck should
    override.
    It refuses while a program is running, and toasts 'still running' rather than
    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
2026-09-17 README: key map, setup on a fresh Mac, and a clean-up pass
    Documents the current key map, including the gestures added since the last
    pass - double-tap X to close a pane, the ENTER+TERM chord, and the fact that
    ENTER, X and MIC change meaning with whatever is running in the pane.
    Adds a setup section aimed at cloning onto a second machine: clone, run, and
    optionally install the launch agent. Both paths were verified from a fresh
    clone rather than written from memory. Also records the two things that cost
    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
2026-09-19 One fullscreen terminal, switched between sessions
    A window per session was built and dropped. It works - each session gets its
    own Space and the keys really are four desktops - but the sessions run either
    way, so the window buys nothing and costs a launch plus a Space animation
    where switching a tmux client is immediate.
    Kept from the detour: raising the window goes through the tmux client's tty,
    walking the process tree to that exact instance, rather than activating by
    app name. With several instances of the same terminal alive macOS picks
    between them arbitrarily, which is what made focus feel unreliable.
    Three findings are now recorded in terminal.py because each broke a guess:
    Ghostty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
